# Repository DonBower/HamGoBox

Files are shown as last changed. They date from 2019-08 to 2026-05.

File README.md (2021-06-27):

# HamGoBox
Ham Radio Go Box

## Objectives:
The Purpose of this Repository is to document the build of the Ham Radio Go Box, which provides for an encapsulated radio that is already hooked up, and requires only power and an antenna.

## Status:
While the display and python3 code are working very well, there is one piece that needs attention: the humidity trend indicator (↑, →, ↓), needs attention.  it should not be changing from rising, stable, falling more than once an hour, but it changes mid minute.

Additionally, I need better documentation to set up the sensors.
Adafruit has made it very easy to install, and I need to reflect that in this repo.

Lastly, again on the documentation front, the STL files for the 3D printed objects need to be better documented.

## Components:
||||
|:---:|:---|:---|
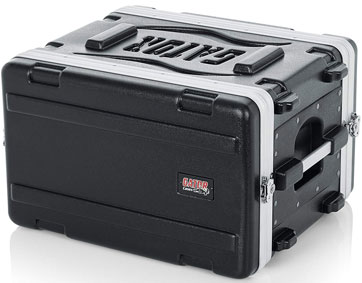
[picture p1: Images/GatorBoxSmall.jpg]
|  | [Gator Box](https://smile.amazon.com/gp/product/B0002BG4O8/ref=ppx_yo_dt_b_asin_title_o08_s04?ie=UTF8&psc=1) | This 6U Portable Rack keeps all of the equipment in one place, and connected. |
|  | [Shelf](https://smile.amazon.com/gp/product/B01C9KYUG8/ref=ppx_yo_dt_b_asin_title_o08_s01?ie=UTF8&psc=1) | The venting on these shelfs will allow for easy bolting down of equipment. |
|  | [Blank](https://smile.amazon.com/gp/product/B06Y1VJD6Q/ref=ppx_yo_dt_b_asin_title_o08_s03?ie=UTF8&psc=1) |These aluminum panels will provide a spot to add some meters, connectors and switches|
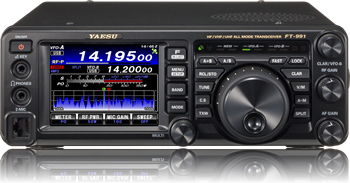
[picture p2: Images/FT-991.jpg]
||[FT-991](https://www.yaesu.com/indexVS.cfm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)|While this radio is no longer in production, a newer version (FT-991A) still is.  This Radio has  160M-6M, 2M & 70CM AM/FM/C4FM/SSB/CW.  There is also a digital mode, which lends this radio to doing PSK and other popular modes of communication.|
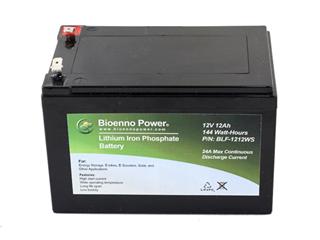
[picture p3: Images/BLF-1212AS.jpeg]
||[BATTERY](https://www.hamradio.com/detail.cfm?pid=H0-014837)|Lightweight 12 Volt/12 Ah battery based on state-of-the-art Lithium Iron Phosphate electrodes.|
|HF Antenna|[G5RVJR](https://www.hamradio.com/detail.cfm?pid=H0-008917)|40 through 6 meters dipole.|
|VHF/UHF Antenna|[NR-770HB](https://www.hamradio.com/detail.cfm?pid=H0-000063)|Diamond VHF/UHF Mobile Antenna.|
|Antenna Mast|[PNH-22](https://www.hamradio.com/detail.cfm?pid=H0-010315)|Lightweight 22' telescoping fiberglass mast.|
|Antenna Stand|[MFJ-1918](https://www.hamradio.com/detail.cfm?pid=H0-007037)|6 Foot Portable Tripod Antenna Stand.|
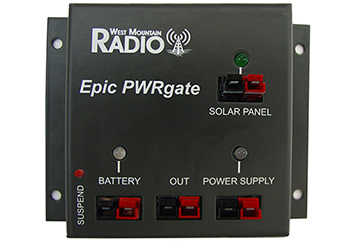
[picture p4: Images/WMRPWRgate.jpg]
||[WMR-Epic PWRgate](https://www.hamradio.com/detail.cfm?pid=H0-015910)|Consolidates power from Battery, Solar and Power Supply sources.  Charges Battery.|
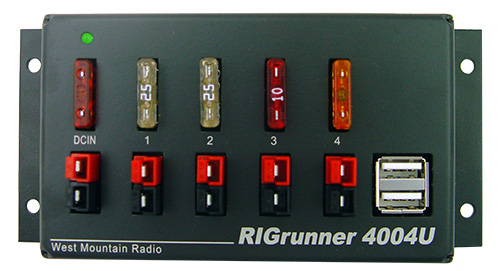
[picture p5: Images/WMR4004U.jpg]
||[WMR-4004U](https://www.hamradio.com/detail.cfm?pid=H0-009867)|Distributes fused power from Power Gate to various pieces of equipment, including Radio, Raspberry Pi, and Monitor.|
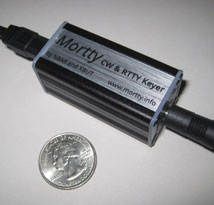
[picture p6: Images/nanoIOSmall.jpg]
||[Keyer](https://hamprojects.info/mortty/)|This Interface is used to enable True Keyed CW when using fldigi. This is a DIY kit, that requires soldering.|
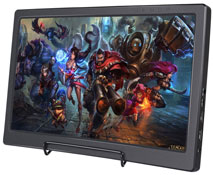
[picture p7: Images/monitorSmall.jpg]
||[Monitor](https://smile.amazon.com/gp/product/B07NNXH2SS/ref=ppx_yo_dt_b_asin_title_o00_s01?ie=UTF8&psc=1)|13 inch high res monitor.|
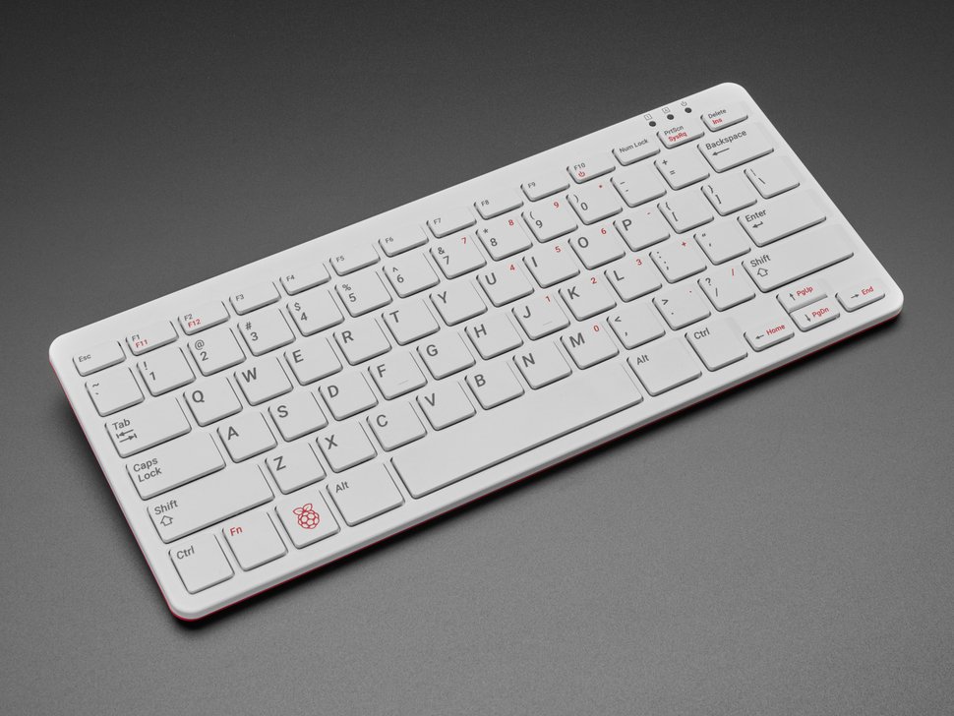
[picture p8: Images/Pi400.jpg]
||[Computer](https://www.adafruit.com/product/4796)|Yea, that's right Computer. With built in Keyboard.  or peraps the other way around. This computer in a keyboard will run all of the software for the Radio (PSK, Logbook, etc...), it has a USB port, a 40 pin GPIO, and and sd-micro for storage.|
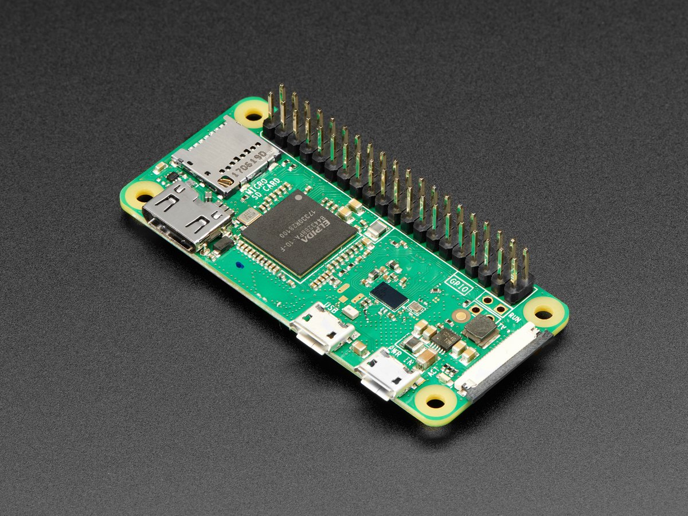
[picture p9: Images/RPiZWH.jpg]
||[Computer](https://www.adafruit.com/product/3708)|This half credit card size computer will run all of the environmental software, it has a USB port, a 40 pin GPIO, and and sd-micro for storage, and it's connected to a boat load of sensors.|
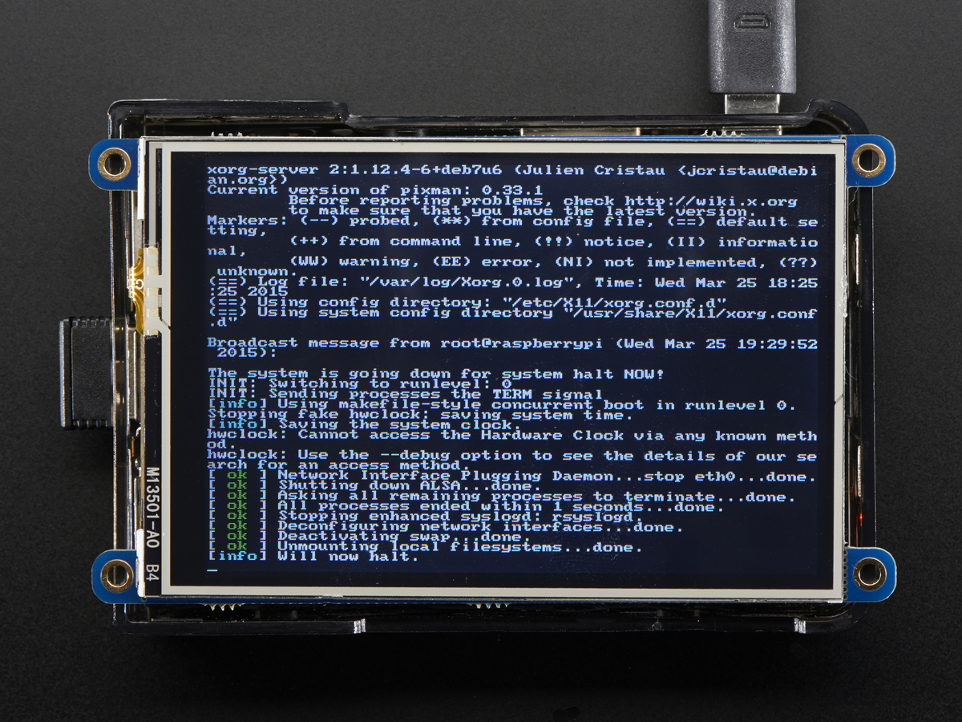
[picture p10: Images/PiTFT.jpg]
||[Display](https://www.adafruit.com/product/2441)|This Display is configured as the Console for the RaspberryPi. It will display all the Environmental information.|
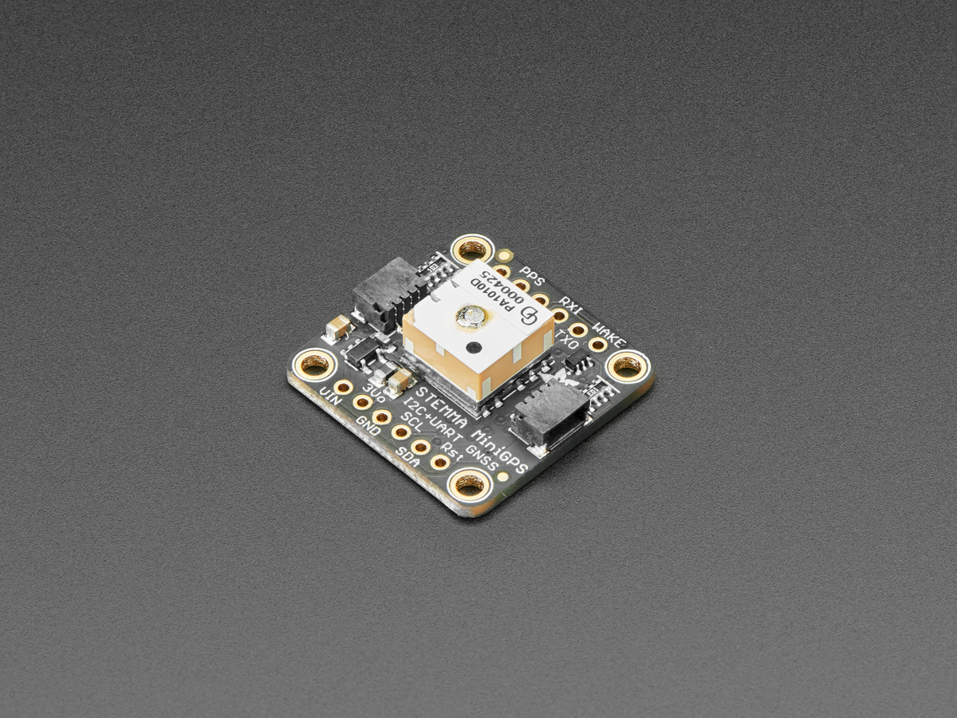
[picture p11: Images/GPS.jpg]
||[GPS Sensor](https://www.adafruit.com/product/4415)|Used to determine precise Latitude and Longitude. From this we can derive the Maidenhead Gridsquare.|
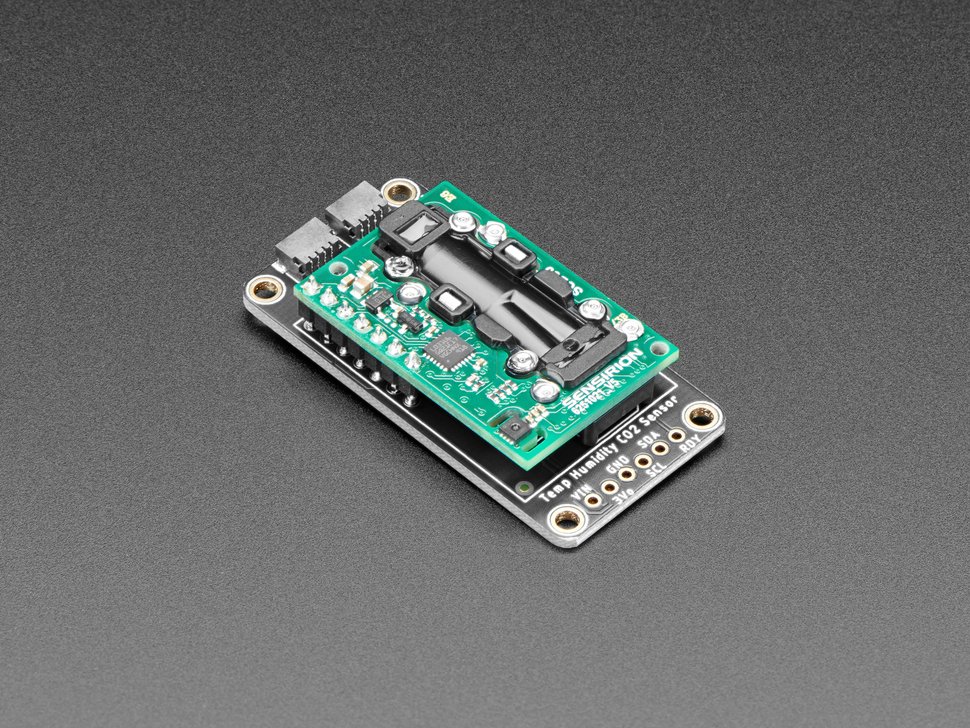
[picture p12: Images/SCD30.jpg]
||[CO2 Sensor](https://www.adafruit.com/product/4867)|The SCD-30 is an NDIR sensor, which is a 'true' CO2 sensor, that will tell you the CO2 PPM (parts-per-million) composition of ambient air. Unlike the SGP30, this sensor isn't approximating it from VOC gas concentration - it really is measuring the CO2 concentration. Perfect for environmental sensing, scientific experiments, air quality and ventilation studies, and more.|
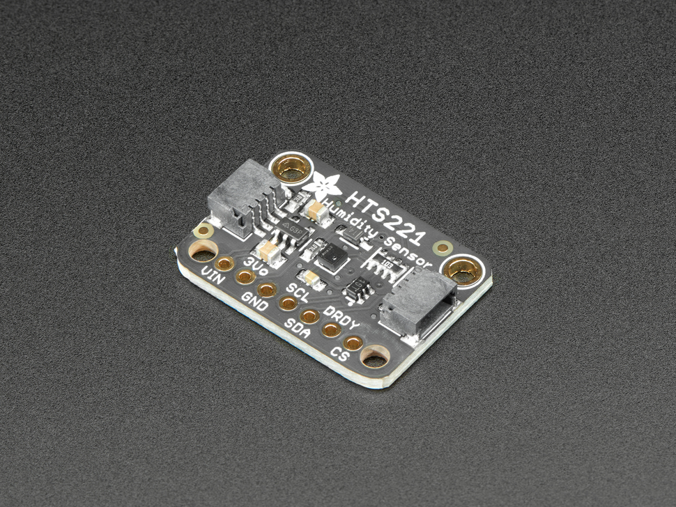
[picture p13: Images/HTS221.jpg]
||[Temperature and Humidity Sensor](https://www.adafruit.com/product/4535)|The HTS221 can measure relative humidity from 0%-100% rH with a sensitivity of 0.004% and 3.5% accuracy between 20-80%. It can also measure temperature from -40 to 120 degrees C, with a resolution of 0.016°C with ±0.5 °C accuracy between 15 and +40 °C.|
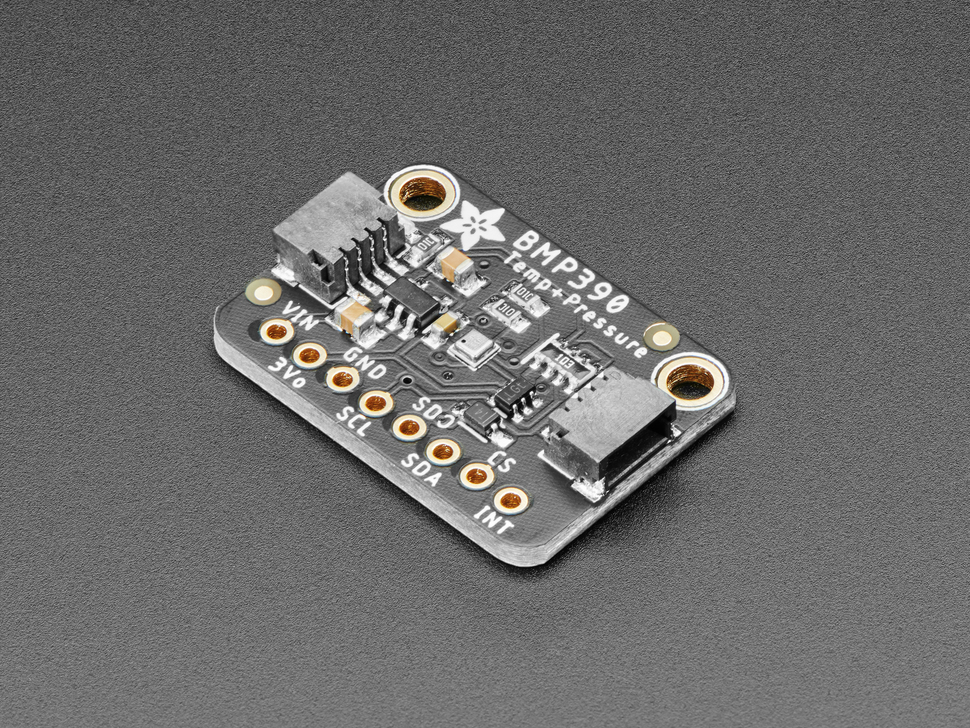
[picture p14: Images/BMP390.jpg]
||[Precision Barometric Pressure Sensor](https://www.adafruit.com/product/4816)|The BMP390L is the next-generation of sensors from Bosch, with a low-altitude noise as low as 0.1m and the same fast conversion time. This sensor has a relative accuracy of ±3 Pascals|
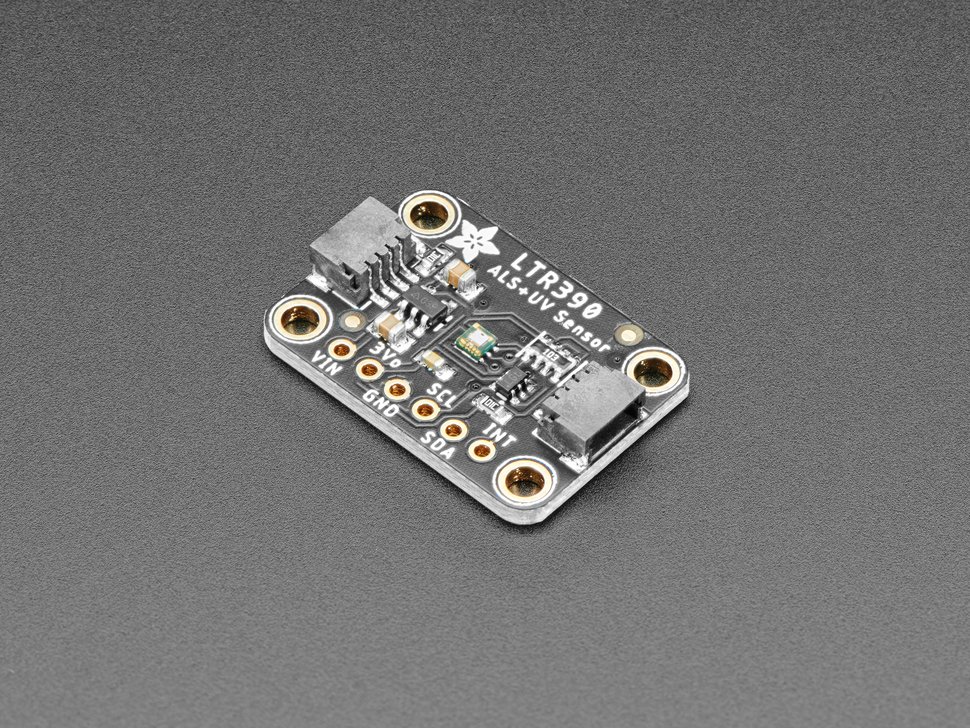
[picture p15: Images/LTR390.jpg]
||[UV Light Sensor](https://www.adafruit.com/product/4831)|The LTR390 has a dedicated  UVA sensor. With both ambient light and UVA sensing with a peak spectral response between 300 and 350nm.|
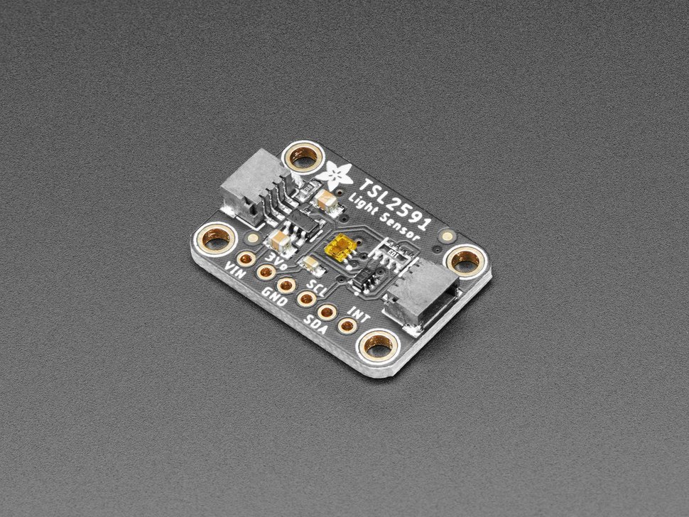
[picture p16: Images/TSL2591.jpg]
||[High Dynamic Range Digital Light Sensor](https://www.adafruit.com/product/1980)|The TSL2591 luminosity sensor is an advanced digital light sensor, ideal for use in a wide range of light situations. This Sensor has a dedicated IR light sensor|

<!---
|![alt text][wmrPNP]|[Interface](https://www.hamradio.com/detail.cfm?pid=H0-008403)|This Interface is capable of converting the audio from software sources such as Ham Radio Deluxe (windows onPNH)22https://www.hamradio.com/detail.cfm?pid=H0-010315.  It's also capable of True Keyed CW when used with HRD, but not fldigi.|
--->

---
## Future Wants
* Weather Conditions -rain? wind?
* Power Monitor V/A/W/Batt lifetime
* CAT Monitor
* Ext Speaker

---
## Assembly

---
## Software Installation
* Setup the RaspberryPi

1. OS. I am going to use Rasbian, the default OS for a RaspberryPi. Start by instsalling [NOOBs](http://downloads.raspberrypi.org/NOOBS_latest). The Setup is described in the [Pi](https://github.com/DonBower/HamGoBox/tree/master/Pi)

1. Programs. I am going to use fldig, flrig and wsjt-x. The Setup is described in [fldig](https://github.com/DonBower/HamGoBox/tree/master/fldigi) and [wsjt-x](https://github.com/DonBower/HamGoBox/tree/master/wsjtx)

1. Location. Precise location is always imperative. So we will use [Adafruit's GPS Hat](https://www.adafruit.com/product/2324). The Setup for this device is described in the [GPS Folder](https://github.com/DonBower/HamGoBox/tree/master/GPSHat)

2. Temperature and Humidity. We will be collecting this information with the [DHT22 Sensor](https://www.adafruit.com/product/385). Because Humidity has an effect on the rate of temperature change, it's important to collect the Relative Humidity. Setup will be found in the [DHT22 Folder](https://github.com/DonBower/HamGoBox/tree/master/DHT22)

3. Temperature and Barometric Pressure. Barometric Pressure also has an effect on Temperature, so we will use the [BMP280 Sensor](https://www.adafruit.com/product/2651) to collect this data.  Setup will be found in the [BMP280 Folder](https://github.com/DonBower/HamGoBox/tree/master/BMP280)

[gatorBox]: https://github.com/DonBower/HamGoBox/blob/master/Images/GatorBoxSmall.jpg "Field Day Box"

[gatorShelf]: https://github.com/DonBower/HamGoBox/blob/master/Images/ShelfSmall.jpg "Rack Shelf"

[gator1UPanel]: https://github.com/DonBower/HamGoBox/blob/master/Images/1UPanelSmall.jpg "Blank Panel"

[yaesuFT897D]: https://github.com/DonBower/HamGoBox/blob/master/Images/FT-897DSmall.jpg "Ham Radio"

[FT-991]: https://github.com/DonBower/HamGoBox/blob/master/Images/FT-991.jpg "Ham Radio"

[BATTERY]: https://github.com/DonBower/HamGoBox/blob/master/Images/BLF-1212AS.jpeg "12V12Ah LiFePo Battery"

[wmrPWRGate]: https://github.com/DonBower/HamGoBox/blob/master/Images/WMRPWRgate.jpg "Epic PWRGate"

[wmr4004U]: https://github.com/DonBower/HamGoBox/blob/master/Images/WMR4004U.jpg "RIGrunner 4004U"

[wmrPNP]: https://github.com/DonBower/HamGoBox/blob/master/Images/WMRPnPSmall.jpg "Digital Mode Interface"

[nanoIO]: https://github.com/DonBower/HamGoBox/blob/master/Images/nanoIOSmall.jpg "CW Keyer"

[raspberryPI]: https://github.com/DonBower/HamGoBox/blob/master/Images/RaspberryPiSmall.jpg "Raspberry Pi"

[raspberryPI400]: https://github.com/DonBower/HamGoBox/blob/master/Images/Pi400.jpg "Raspberry Pi 400"

[monitor]: https://github.com/DonBower/HamGoBox/blob/master/Images/monitorSmall.jpg "Monitor"

[raspberryPIZero]: https://github.com/DonBower/HamGoBox/blob/master/Images/RPiZWH.jpg "Raspberry Pi Zero"

[PiTFT]: https://github.com/DonBower/HamGoBox/blob/master/Images/PiTFT.jpg "Raspberry Pi TFT"

[GPS]: https://github.com/DonBower/HamGoBox/blob/master/Images/GPS.jpg "Mini GPS Sensor"

[SCD-30]: https://github.com/DonBower/HamGoBox/blob/master/Images/SCD30.jpg "NDIR CO2 Sensor"

[HTS221]: https://github.com/DonBower/HamGoBox/blob/master/Images/HTS221.jpg "Temperature & Humidity Sensor"

[BMP390]: https://github.com/DonBower/HamGoBox/blob/master/Images/BMP390.jpg "Precision Barometric Pressure and Altimeter Sensor"

[LTR390]: https://github.com/DonBower/HamGoBox/blob/master/Images/LTR390.jpg "UV Light Sensor"

[TSL2591]: https://github.com/DonBower/HamGoBox/blob/master/Images/TSL2591.jpg "High Dynamic Range Digital Light Sensor"

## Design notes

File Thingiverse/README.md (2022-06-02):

You can also find these .STL files on thingiverse:

[West Mountain Brackets](https://www.thingiverse.com/thing:4728897)

[Front Plate](https://www.thingiverse.com/thing:4786908)

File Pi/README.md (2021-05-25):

# Install the RaspberryPi Imager
Raspberry Pi Imager is the quick and easy way to install Raspberry Pi OS and other operating systems to a microSD card, ready to use with your Raspberry Pi. [Watch their 40-second video](https://www.youtube.com/watch?v=J024soVgEeM) to learn how to install an operating system using Raspberry Pi Imager.

Download and install Raspberry Pi Imager to a computer with an SD card reader. Put the SD card you'll use with your Raspberry Pi into the reader and run Raspberry Pi Imager.

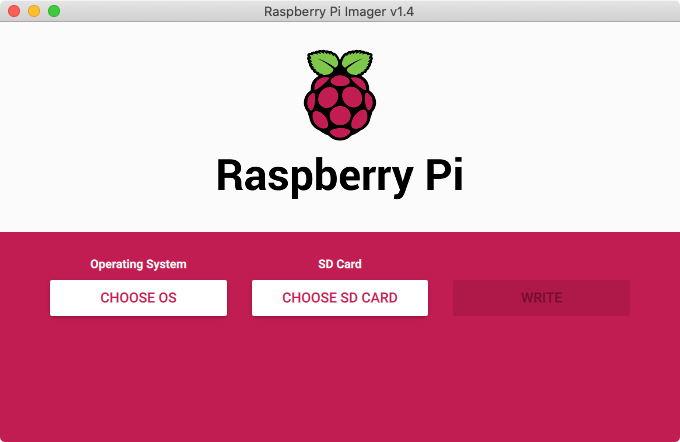
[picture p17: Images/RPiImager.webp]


Install the [RaspberryPi Imager](https://www.raspberrypi.org/software/):

* Install on another Raspberry Pi with GUI: run `sudo apt install rpi-imager` in a terminal window

* [Download for macOS](https://downloads.raspberrypi.org/imager/imager_1.5.dmg)

* [Download for Ubuntu_x86](https://downloads.raspberrypi.org/imager/imager_1.5_amd64.deb)

* [Download for Windows](https://downloads.raspberrypi.org/imager/imager_1.5.exe)

[Imager]: https://github.com/DonBower/HamGoBox/blob/master/Images/RPiImager.webp "RaspberryPi Imager"

# Install RasbianOS Lite
Be sure to choose the Lite Version of RasbianOS, because we will not be running a Gui from the RaspberryPi Zero.

Burn the OS image to your MicroSD card using your computer

Re-plug the SD card into your computer (don't use your Pi yet!)

Set up your wifi by copying the file [wpa_supplicant.conf](https://github.com/DonBower/HamGoBox/blob/master/Pi/wpa_supplicant.conf) to the sd card and then edit the file, replacing the <> values with your WiFi name and password.

Create an empty file called ssh on the sd card.
```
touch /Volumes/boot/ssh
```
This enables the ssh protocol on the RaspberryPi, which is good, because there is no GUI on this machine.

Eject the SD Card from your PC, and plug it into the Pi

If you have an HDMI monitor we recommend connecting it so you can see that the Pi is booting OK

Plug in power to the Pi - you will see the green LED flicker a little. The Pi will reboot while it sets up so wait a good 10 minutes

If you are running Windows on your computer, install Bonjour support so you can use .local names, you'll need to reboot Windows after installation

You can now ssh into raspberrypi.local
`ssh pi@raspberrypi.local`

# Set Hostname
```
sudo sed -i 's/raspberrypi/goboxpi/g' /etc/hosts
sudo sed -i 's/raspberrypi/goboxpi/g' /etc/hostname
sudo shutdown -r now
```

The Pi will reboot so log back in with `ssh pi@goboxpi.local`

# SSH Interface

Next order of business is get a ssh key. (Take all defaults)

```
ssh-keygen
```
Now, log out of the session with `exit` and copy the public key on your linux based machine to the RaspberryPi, so you don't have to use a password each time you log in.

```
ssh-copy-id -i ~/.ssh/id_rsa.pub pi@goboxpi.local
```

Copy the public SSH key to GitHub per the instructions documented in https://help.github.com/articles/adding-a-new-ssh-key-to-your-github-account/<br>

# Firmware/OS Updates

Next we update/upgrade the OS to the latest version, as well as the RaspberryPi Firmware.  <br />

```
sudo apt-get --assume-yes update
sudo rpi-update
```

At this point, your system may have actually performed a firmware update.  And a brave man may continue on and reboot later.  I am not that brave. `sudo shutdown -r now` if you are so inclined.

```
sudo apt-get --assume-yes upgrade
sudo apt-get --assume-yes dist-upgrade
sudo shutdown -r now
```

# Set Timezone

Set the Timezone

```
sudo timedatectl set-timezone America/Los_Angeles
```

# Git/GitHub

Then it's time to get git, and configure the git Global Variables <br />
(note: use your own name and email...)

```
sudo apt-get --assume-yes install git
git config --global user.name "Don Bower"
git config --global user.email "Don.Bower@outlook.com"
```

Next Create a *Developer* directory, and clone this repository from there.  The *Developer* directory is standard practice for modern developers. Some use lowercase for the name, but since on the RaspberryPi, and my Mac, all the other preloaded directories are capitalized, (i.e. Documents, Pictures, etc...) I'll follow form. <br />

```
mkdir ~/Developer
cd ~/Developer
git clone git@github.com:DonBower/HamGoBox.git
```

If you need updates from github, use git pull:

```
cd ~/Developer/HamGoBox
git pull
```

# Setup Tools

```
sudo pip3 install --upgrade setuptools
```
If above doesn't work, install pip3 and try again.

```
sudo apt-get install python3-pip
```
Adafruit put together a script to easily make sure your Pi is correctly configured and install Blinka. It requires just a few commands to run. Most of it is installing the dependencies.
```
cd ~
sudo pip3 install --upgrade adafruit-python-shell
wget https://raw.githubusercontent.com/adafruit/Raspberry-Pi-Installer-Scripts/master/raspi-blinka.py
sudo python3 raspi-blinka.py
```
select Y for any prompts.
after the RaspberryPi has rebooted, run this Test to confirm all the interfaces were installed and enabled

The [I&#x00B2;C (Inter-Integrated Circuit)](https://en.wikipedia.org/wiki/I%C2%B2C) and spi interfaces should now be installed and enabled.

You can run the following command to verify:
```
python3 Developer/HamGoBox/Pi/blinkatest.py
```

You can run the following command to verify:
```
ls /dev/i2c* /dev/spi*
```
You should see the response
```
/dev/i2c-1 /dev/spidev0.0 /dev/spidev0.1
```

# Python SMBUS and I&#x00B2;C Interface tools
To view the [I&#x00B2;C (Inter-Integrated Circuit)](https://en.wikipedia.org/wiki/I%C2%B2C)
devices that are connected, execute the following:
```
sudo i2cdetect -y 1
```
Your output will look similar to the following:
```
     0  1  2  3  4  5  6  7  8  9  a  b  c  d  e  f
00:          -- -- -- -- -- -- -- -- -- -- -- -- --
10: 10 -- -- -- -- -- -- -- -- -- -- -- -- -- -- --
20: -- -- -- -- -- -- -- -- -- 29 -- -- -- -- -- --
30: -- -- -- -- -- -- -- -- -- -- -- -- -- -- -- --
40: -- -- -- -- -- -- -- -- -- -- -- -- -- -- -- --
50: -- -- -- 53 -- -- -- -- -- -- -- -- -- -- -- 5f
60: -- 61 -- -- -- -- -- -- -- -- -- -- -- -- -- --
70: -- -- -- -- -- -- -- 77                         
```
all of the non "--" entries represent a device detected.

# Install CircuitPython Libraries for the sensors:

```
sudo pip3 install adafruit-circuitpython-gps \
 adafruit-circuitpython-bmp3xx \
 adafruit-circuitpython-hts221 \
 adafruit-circuitpython-tsl2591 \
 adafruit-circuitpython-ltr390 \
 adafruit-circuitpython-scd30
```

Test Which sensors are installed:
```
python3 ~/Developer/HamGoBox/Pi/sensortest.py
```

# Install TFT Display as the console.

```
cd ~
sudo pip3 install --upgrade adafruit-python-shell click==7.0
sudo apt-get install -y git
git clone https://github.com/adafruit/Raspberry-Pi-Installer-Scripts.git
cd Raspberry-Pi-Installer-Scripts
sudo python3 adafruit-pitft.py --display=35r --rotation=90 --install-type=console
```

# Install Blinka from Adafruit
```
cd ~
sudo pip3 install --upgrade adafruit-python-shell
wget https://raw.githubusercontent.com/adafruit/Raspberry-Pi-Installer-Scripts/master/raspi-blinka.py
sudo python3 raspi-blinka.py
```

# Get/Update Libraries from Adafruit
Run the following command to get the latest Libraries.
```
./getAdafruitLibraries.sh
```

It will product output that ends like this:
```
The Following Libraries were updated:

| Library                        | From   | To     |
| ------------------------------ | ------ | ------ |
| Adafruit-Blinka                | 5.13.0 | 6.9.1  |
| adafruit-circuitpython-bmp3xx  | 1.3.2  | 1.3.6  |
| adafruit-circuitpython-gps     | 3.6.7  | 3.9.0  |
| adafruit-circuitpython-hts221  | 1.1.2  | 1.1.5  |
| adafruit-circuitpython-scd30   | 2.0.0  | 2.1.0  |
| adafruit-circuitpython-tsl2591 | 1.2.5  | 1.3.0  |
| Adafruit-PlatformDetect        | 2.28.0 | 3.13.1 |
```

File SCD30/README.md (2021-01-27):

# CO2 Sensor

```
sudo pip3 install adafruit-circuitpython-scd30
```

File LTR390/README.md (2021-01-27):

# UV Light Sensor
```
sudo pip3 install adafruit-circuitpython-ltr390
```

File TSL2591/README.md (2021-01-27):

# TSL2591 Circuit Python library
```
sudo pip3 install adafruit-circuitpython-tsl2591
```

This is a simple python library for the Adafruit TSL2591 breakout board based on the [Arduino library](https://github.com/adafruit/Adafruit_TSL2591_Library) from Adafruit. It was developed to work on a Raspberry PI.

# INFO

Enabeling I2C on the Raspberry Pi. You should be fine by following the instruction on [Adafruit](https://learn.adafruit.com/adafruits-raspberry-pi-lesson-4-gpio-setup/configuring-i2c).

In the last step ('Testing I2C') you should see at least one connected device, your TSL2591 (most likely at 0x29 ).

## Installing ##

To install the python module you first need to install the ibffi-dev package, then compile the driver.

```
sudo apt-get install libffi-dev
sudo python setup.py install
sudo python3 setup.py install
```

## Quickstart ##

```
import tsl2591

tsl = tsl2591.Tsl2591()  # initialize
full, ir = tsl.get_full_luminosity()  # read raw values (full spectrum and ir spectrum)
lux = tsl.calculate_lux(full, ir)  # convert raw values to lux
print lux, full, ir
```

## License ##

Python files in this repository are released under the [MIT license](LICENSE.md).

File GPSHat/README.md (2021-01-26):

# I2C Usage:
```
sudo pip3 install adafruit-circuitpython-gps
```
Way cooler than using an onboard UART you have to futz with, but if you want to go that route:

# The Right UART
So Here is my quest to use the Adafruit Ultimate GPS which comes in 2 flavors,   <br>
one is a [breakout](https://www.adafruit.com/products/746), and the other is a [hat](https://www.adafruit.com/products/2324). <br>
The issue with these two products working straight out of the box (with the pi 3) are <br>
1. The UART configured to use the GPIO is disabled <br>
2. The default UART for the GPIO is a mini-UART (i.e. software assisted)<br>
3. The Hardware UART is enabled and configured to use bluetooth.<br>

There is a fantastic write-up on how to get things back on track, which I am ultimately going to follow:  <br>
http://spellfoundry.com/2016/05/29/configuring-gpio-serial-port-raspbian-jessie-including-pi-3  <br>
<br>
First, I am using a [Raspberry Pi 3+](https://www.adafruit.com/products/3055).

<br>
With the Jessie Version of Raspian on my Pi3, the default serial port configuration is:<br>

* `/dev/serial0 -> ttyS0`
  * a.k.a. mini-UART
  * Is configured for GPIO
  * Is disabled
  * uses the service getty to provide console access

* `/dev/serial1 -> ttyAMA0`
  * Is configured for bluetooth
  * Is enabled<br>

These points are demonstrated by displaying the current status of the serial ports:
```
pi@raspberrypi:~/balloon $ ls -l /dev/ser*
lrwxrwxrwx 1 root root 7 Aug 25 03:46 /dev/serial1 -> ttyAMA0
```
We enable the GPIO UART by adding the line `enable_uart=1` to the bottom of <b>/boot/config.txt</b> file and reboot.<br>
<br>
Now we can see both UARTs enabled, but backwards for our purposes:
```
pi@raspberrypi:~/balloon $ ls -l /dev/ser*
lrwxrwxrwx 1 root root 5 Aug 26 02:48 /dev/serial0 -> ttyS0
lrwxrwxrwx 1 root root 7 Aug 26 02:48 /dev/serial1 -> ttyAMA0
```
<br>
Now it's time to stop the console service, which is unnecessary for the balloon project:<br>

```
sudo systemctl stop serial-getty@ttyS0.service
sudo systemctl disable serial-getty@ttyS0.service
```
<br>

Now, let's not reference the console service in future boots.<br>
Remove the `console=serial0,115200` entry from the <b>/boot/cmdline.txt</b> file, and reboot.<br>
<br>
Here is my new <b>/boot/cmdline.txt</b> file:

```
dwc_otg.lpm_enable=0 console=tty1 root=/dev/mmcblk0p7 rootfstype=ext4 elevator=deadline fsck.repair=yes rootwait
```

<br>
Finally we can swap the bluetooth port with the mini-UART by adding the line `dtoverlay=pi3-miniuart-bt` to the bottom of <b>/boot/config.txt</b> and reboot. <br>
<br>

Viola!<br>

```
pi@raspberrypi:~ $ ls -l /dev/ser*
lrwxrwxrwx 1 root root 7 Aug 26 03:24 /dev/serial0 -> ttyAMA0
lrwxrwxrwx 1 root root 5 Aug 26 03:24 /dev/serial1 -> ttyS0
```

Next we need to install the GPS daemon, gpsd. To install gpsd, simply run the following commands from the console:
```
sudo apt-get update
sudo apt-get install gpsd gpsd-clients python-gps
```

This will install the required packages (an internet connection will be required for this step!)
Raspbian Jessie systemd service fix

Now, disable a systemd service that gpsd installs. This service has systemd listen on
a local socket and run gpsd when clients connect to it, however it will also interfere with other gpsd instances that are manually run (like in this guide).

To disable the gpsd systemd service by running the following commands:
```
sudo systemctl stop gpsd.socket
sudo systemctl disable gpsd.socket
```

After disabling the gpsd systemd service above you're ready to try running gpsd manually. Now run the following command to manually start gpsd and
point it at the GPS breakout on the USB serial adapter port:
```
sudo gpsd /dev/ttyAMA0 -F /var/run/gpsd.sock
```

... which will point the gps daemon to our GPS device on the onboard serial UART.

Testing it Out<br>
After a few seconds, gpsd should open up the proper socket and if the GPS has locked on to a minimum number of satellites, we should be able to get some data from the GPS module.
To test this, we can use the following command:
```
cgps -s
```

If you have a fix, you'll see something like the following information in the terminal window:
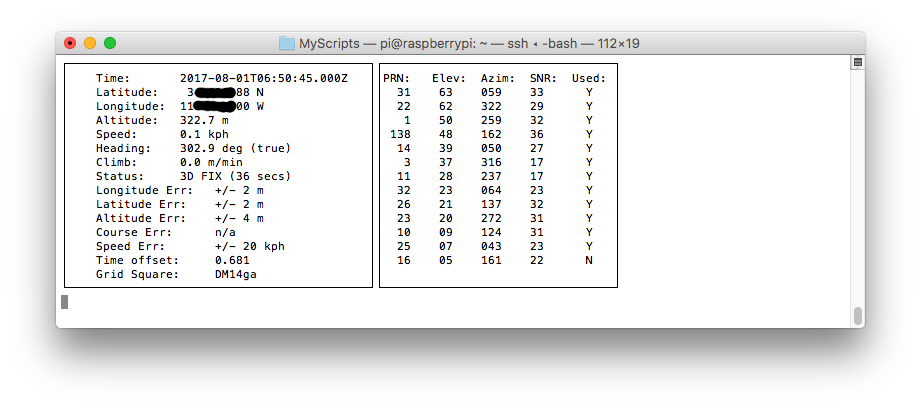
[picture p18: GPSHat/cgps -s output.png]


[logo]: https://github.com/DonBower/Eclipse2017/blob/master/GPSHat/cgps%20-s%20output.png "cgps -s output"

<br>

You will need to install a couple more packages to get the rungps.sh script to work:

```
sudo apt install bc
```
<br>

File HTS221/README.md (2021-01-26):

# Install Libraries

```
sudo pip3 install adafruit-circuitpython-hts221
```

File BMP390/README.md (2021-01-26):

# Tempature and Barametric Pressure sensor
Install with these commands<br>
```
sudo pip3 install adafruit-circuitpython-bmp3xx
```
Then you can run a simple test:
```
sudo python3 simpletest.py
```
Here is what mine looks like:
```
pi@raspberrypi:~/Adafruit_Python_BMP/examples $ sudo python simpletest.py
Temp = 24.50 *C
Pressure = 97255.00 Pa
Altitude = 343.12 m
Sealevel Pressure = 97270.00 Pa
```

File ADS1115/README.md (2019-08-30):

# ADS1115 Analog - Digital converter

# Adafruit Python ADS1x15
Python code to use the ADS1015 and ADS1115 analog to digital converters with a Raspberry Pi or BeagleBone black.

## Installation

To install the library from source (recommended) run the following commands on a Raspberry Pi or other Debian-based OS system:

    sudo apt-get install git build-essential python-dev
    cd ~/Developer/github/adafruit
    git clone https://github.com/adafruit/Adafruit_Python_ADS1x15.git
    cd Adafruit_Python_ADS1x15
    sudo python setup.py install

Alternatively you can install from pip with:

    sudo pip install adafruit-ads1x15

Note that the pip install method **won't** install the example code.

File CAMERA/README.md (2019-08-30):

CAMERA CONFIGURATION

SETTING UP THE CAMERA HARDWARE

Warning: Cameras are sensitive to static. Earth yourself prior to handling the PCB. A sink tap or similar should suffice if you don’t have an earthing strap.

The camera board attaches to the Raspberry Pi via a 15-way ribbon cable. There are only two connections to make: the ribbon cable needs to be attached to the camera PCB, and to the Raspberry Pi itself. You need to get the cable the right way round, or the camera will not work. On the camera PCB, the blue backing on the cable should face away from the PCB, and on the Raspberry Pi it should face towards the Ethernet connection (or where the Ethernet connector would be if you're using a model A).

Although the connectors on the PCB and the Pi are different, they work in a similar way. On the Raspberry Pi itself, pull up the tabs on each end of the connector. It should slide up easily, and be able to pivot around slightly. Fully insert the ribbon cable into the slot, ensuring it is set straight, then gently press down the tabs to clip it into place. The camera PCB connector also requires you to pull the tabs away from the board, gently insert the cable, then push the tabs back. The PCB connector can be a little more awkward than the one on the Pi itself.

SETTING UP THE CAMERA SOFTWARE

Execute the following instructions on the command line to download and install the latest kernel, GPU firmware, and applications. You'll need an internet connection for this to work correctly.

```
sudo apt-get update
sudo apt-get upgrade
```

Now you need to enable camera support using the raspi-config program you will have used when you first set up your Raspberry Pi.

```
sudo raspi-config
```

Use the cursor keys to move to the camera option, and select 'enable'. On exiting  raspi-config, it will ask to reboot. The enable option will ensure that on reboot the correct GPU firmware will be running with the camera driver and tuning, and the GPU memory split is sufficient to allow the camera to acquire enough memory to run correctly.

To test that the system is installed and working, try the following command:

```
raspistill -v -o test.jpg
```

The display should show a five-second preview from the camera and then take a picture, saved to the file `test.jpg`, whilst displaying various informational messages.

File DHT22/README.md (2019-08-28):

# DHT-22 Tempature and humidity sensor
Install the Adafruit DHT library:
```
git clone https://github.com/adafruit/Adafruit_Python_DHT.git
cd Adafruit_Python_DHT
sudo python setup.py install
```
Not much to that!

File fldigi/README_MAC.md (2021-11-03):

# Connect FLDIGI on the Macbook Pro with Big Sur (11.5.2) to Yaesu FT-991 (non-A)

## Load CP210x VCP Drivers 
If you have not already done so, or did with a version prior to 6.0.1, follow these steps 
1. Disconnect everything from the MacBook except LAN/WiFi
1. Reboot.
1. Download **CP210x VCP Mac OSX Driver** from [Silicon Labs Download page](https://www.silabs.com/developers/usb-to-uart-bridge-vcp-drivers)
1. Unzip the `Mac_OSX_VCP_Driver.zip` file
1. Launch the `SiLabsUSBDriverDisk.dmg` file by double clicking on it from **Finder**
    1. If you have a previous version of the driver, 
        1. Double click the uninstaller.sh and follow the prompts.
        1. Reboot, and follow the next step.
    1. Double click the `Install CP210x VCP Driver.app` file
        1. Follow the Prompts
1. Reboot.

## Configure the Radio
To Configure the Radio, you can change the Menu items as follows. In the Menu, default values appear as blue.
|Menu Item #|Menu Item Name|Item Value Range|Default Value|Prefered Value|
|---:|:---|---|---|:---:|
|31|CAT RATE|4800/9600/19200/38400 bps|4800 bps|**38400 bps**|
|32|CAT TOT|10/100/1000/3000 msec|10 msec|10 msec|
|33|CAT RTS|ENABLE/DISABLE|ENABLE|ENABLE|
|46|AM OUT LEVEL|0-100|50|**100**|
|59|CW FREQ DISPLAY|DIRECT FREQ/PITCH OFFSE|PITCH OFFSE|PITCH OFFSE|
|60|PC KEYING|OFF/DAKY/RTS/DTR|OFF|**DTR**|
|62|DATA MODE|PSK/OTHERS|PSK|**OTHERS**|
|63|PSK TONE|1000/1500/2000 Hz|1000 Hz|**1500 Hz**|
|64|OTHER DISP (SSB)|-3000 - 0 - 3000 10Hz Step|0 Hz|**1500 Hz**|
|65|OTHER SHIFT (SSB)|-3000 - 0 - 3000 10Hz Step|0 Hz|**1500 Hz**|
|66|DATA LCUT FREQ|OFF/100-1000 (50Hz Step)|300 Hz|300 Hz|
|67|DATA LCUT SLOPE|6 dB/oct / 18 dB/oct|18 dB/oct|18 dB/oct|
|68|DATA HCUT FREQ|700-4000 (50Hz Step)|3000 Hz|**3600 Hz**|
|69|DATA HCUT SLOPE|6 dB/oct / 18 dB/oct|18 dB/oct|18 dB/oct|
|70|DATA IN SELECT|REAR/MIC|REAR|REAR|
|71|DATA PTT SELECT|DAKY/RTS/DTR|DAKY|**DTR**|
|72|DATA PORT SELECT|DATA/USB|DATA|**USB**|
|73|DATA OUT LEVEL|0-100|50|**100**|
|74|FM MIC SELECT (PHONE)|MIC/REAR|MIC|MIC|
|75|FM OUT LEVEL|0-100|50|50|
|76|FM PKT PTT SELECT|DAKY/RTS/DTR|DAKY|**DTR**|
|77|FM PKT PORT SELECT|DATA/USB|DATA|DATA|
|106|SSB MIC SELECT|MIC/REAR|MIC|MIC|
|107|SSB OUT LEVEL|0-100|50|50|
|108|SSB PTT SELECT|DAKY/RTS/DTR|DAKY|DAKY|
|109|SSB PORT SELECT|DATA/USB|DATA|**USB**|
|110|SSB TX BPF|100-3000/100-2900/200-2800/300-2700/400-2600|300-2700|300-2700|
|114|IF NOTCH WIDTH|NARROW/WIDE|WIDE|**NARROW**|
|141|TUNER SELECT|OFF/INTERNAL/EXTERNAL/ATAS/LAMP|INTERNAL|**ATAS**|
|146|DATA VOX GAIN|0-100|50|50|
|147|DATA VOX DELAY	100|30-3000 msec|100 msec|100 msec|
|148|ANTI DVOX GAIN|0-100|0|0|
||||||

## Connect the FT-991 Radio
Use the [RT-42 USB-A to USB-B 6-Ft Cable](https://www.rtsystemsinc.com/RT-42-USB-A-to-USB-B-6-Ft-Cable_p_542.html) cable from RT Systems<br>
Open a terminal window and type `ls -l /dev/cu.*`
you should see the following:
```
don@MacbookPro ~ % ls -l /dev/cu.*
crw-rw-rw-  1 root  wheel    9,   1 Sep 14 15:31 /dev/cu.Bluetooth-Incoming-Port
crw-rw-rw-  1 root  wheel    9,   3 Sep 14 16:54 /dev/cu.SLAB_USBtoUART
crw-rw-rw-  1 root  wheel    9,   5 Sep 14 17:37 /dev/cu.SLAB_USBtoUART2
```

The FT-991, and other radios that have an intergrated sound card (FTdx-3000, FTdx-10D), along with the SCU-17 contain two virtual COM ports, an Enhanced COM port and a Standard COM Port, which are rendered by the SiliconLabs VCP Driver as `/dev/cu.SLAB_USBtoUART` and `/dev/cu.SLAB_USBtoUART2`  These ports offer the following functions:
  * CAT communications..................: Enhanced COM Port
  * TX control (PTT, KEY, FSK)..........: Standard COM Port

`<rant>`<br>
For the macOS Big Sur, it is not possiable, as it is in Windows, along with Ubuntu, Raspberry PI and other Linux distributions, to coerce the driver to render one to `/dev/cu.SLAB_USBtoUART` and the other to `/dev/cu.SLAB_USBtoUART2` at this time.

These devices can "swap" themselfs between macOS boots and reconnection of the radio.
if you examine the System Information for USB, you will see:
```
CP2105 Dual USB to UART Bridge Controller:

  Product ID:	0xea70
  Vendor ID:	0x10c4  (Silicon Laboratories, Inc.)
  Version:	1.00
  Serial Number:	AH057M5I150492
  Speed:	Up to 12 Mb/s
  Manufacturer:	Silicon Labs
  Location ID:	0x14110000 / 2
  Current Available (mA):	500
  Current Required (mA):	100
  Extra Operating Current (mA):	0
```
with the only indication that there are 2 devices here is the `/ 2` at `Location ID:`.

Given that other operating systems are able to coerce and/or identify these two different ports, one can only conclude Silicon Labs has not invested enough effort into this issue, nor is Apple innocent in removing the udev functionality. 
<br>`</rant>`

## Configure flrig 1.4.2
1. Download [flrig 1.4.2](http://www.w1hkj.com/files/flrig/flrig-1.4.2_bs.dmg) for Big Sur.
- _bs is for Big Sur, 11.x
- _hs is for macOS High Sierra, 10.13.x 
- _lion is for macOS Lion, 10.7.x
1. Open the .dmg file and copy the app to your /Applications folder
1. Open the flrig application from the Launchpad
1. Open the Config menu and select Setup>Transceiver<br>
Set the values as show in the graphic:
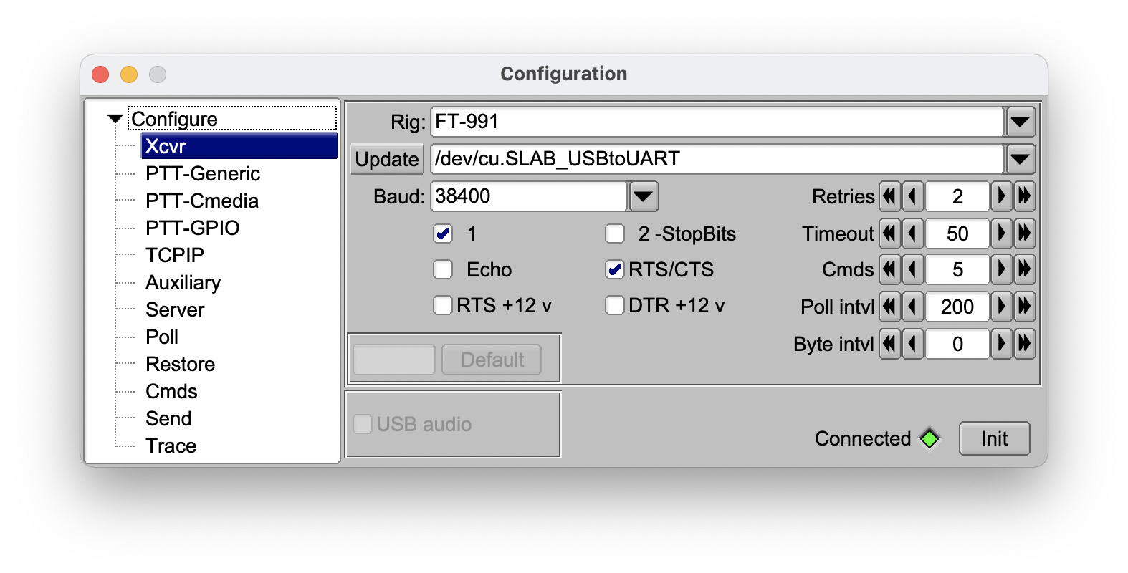
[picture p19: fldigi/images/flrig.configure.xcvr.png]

1. Click the [init] button<br>
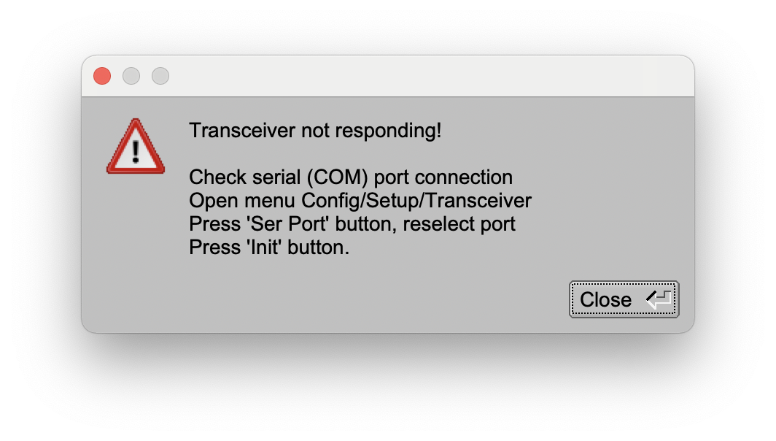
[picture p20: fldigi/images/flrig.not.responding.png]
If you this pop-up <br> then choose the other cu.SLAB device.  It is not possiable at this time to configure the macbook to predict which cu.SLAB device is the "enhanced" port, which provides CAT operations with the radio.  In fact, this assignment can change between reboots of the computer, and re-connection of the radio.  It's a huge dis-advantage to macOS, which Windows, Ubuntu and Raspberry Pi are able to deal with for better consistancy.
So if your radio works today, but won't conecct tomorrow, swap these two values, and click the [init] button again.<br>
1. Select Setup>PTT-Generic from the Config menu<br>
Set the values as show in the graphic:
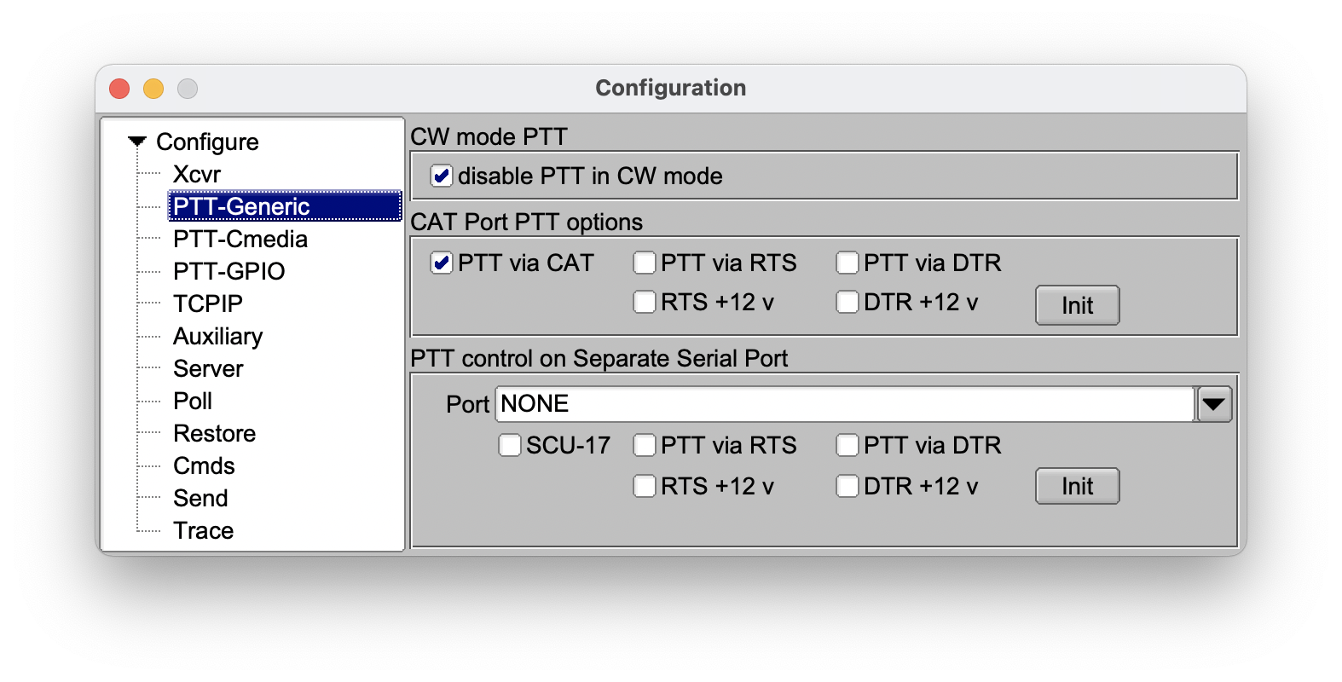
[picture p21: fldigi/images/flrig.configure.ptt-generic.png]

1. Select Setup>TCPIP from the Config menu<br>
Set the values as show in the graphic:
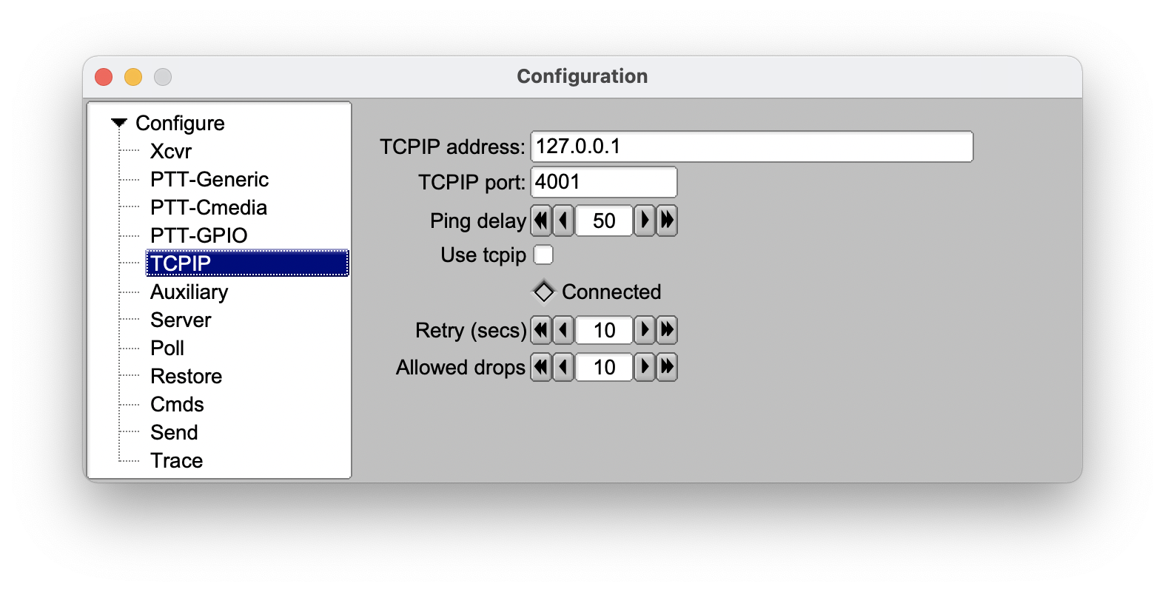
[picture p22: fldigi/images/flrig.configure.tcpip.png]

1. Select Setup>Poll from the Config menu<br>
Set the values as show in the graphic:
![alt-text][flrig.config.poll]
1. Select Setup>Restore from the Config menu<br>
Set the values as show in the graphic:
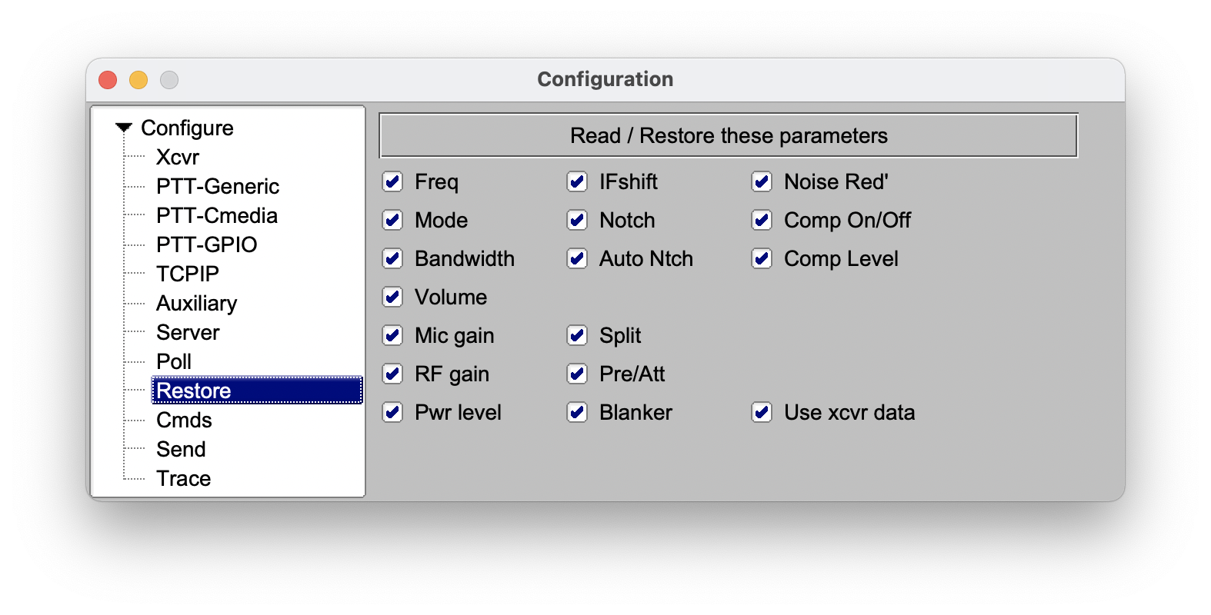
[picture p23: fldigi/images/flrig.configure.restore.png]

<br>
When Complete, close the Configuartion Pop-Up, and you should see this:
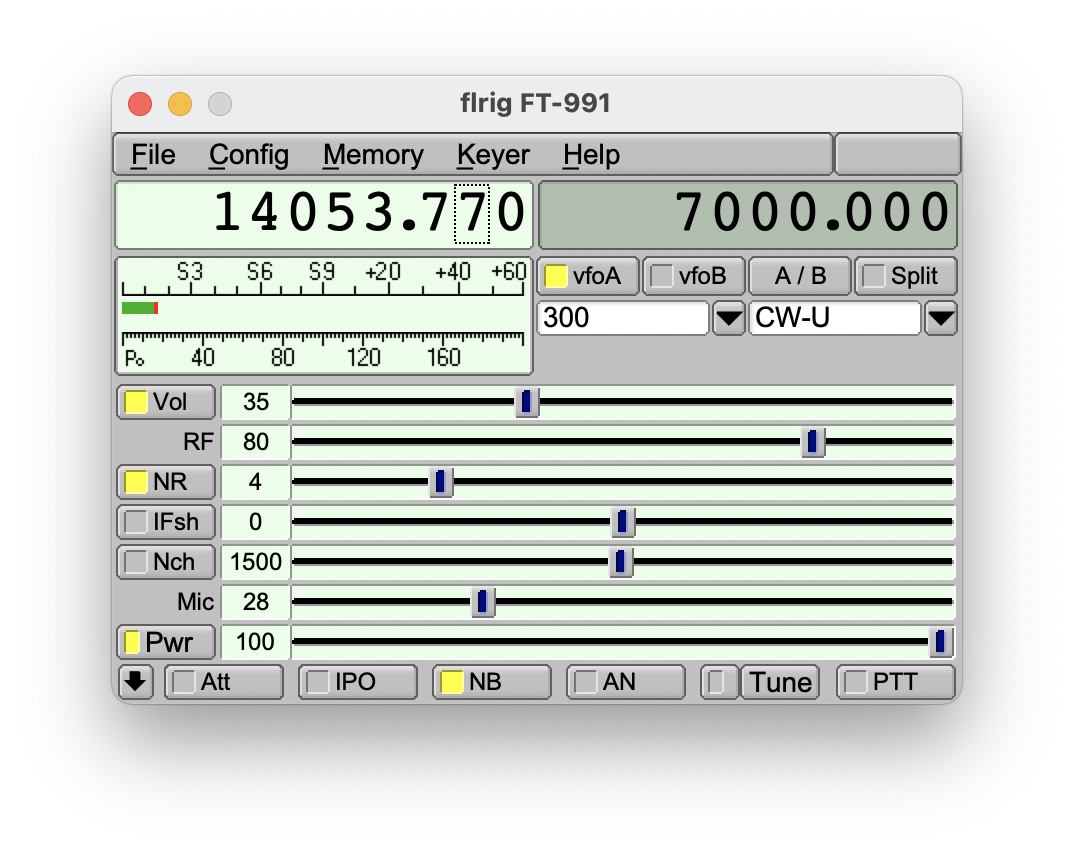
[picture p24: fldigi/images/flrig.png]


## Configure fldigi 4.1.20
1. Download [fldigi 4.1.29](http://www.w1hkj.com/files/fldigi/fldigi-4.1.20_bs.dmg) for Big Sur.
- _bs is for Big Sur, 11.x
- _hs is for macOS High Sierra, 10.13.x 
- _lion is for macOS Lion, 10.7.x
1. Open the .dmg file and copy the app to your /Applications folder
1. Open the fldigi application from the Launchpad

## Using the FT-991A with fldigi and flrig

CAT control involves both software and settings on the radio itself. The default radio settings on the FT-991 are not likely to work “out of the box”.

Some initial things to verify are in place:

1. Download and install the USB driver for the radio. NOTE: be sure the USB cable is UNPLUGGED from the
computer when you install the driver regardless of the OS your are using.
- If you’re using Windows get the driver from Icom or use the one on the CD that comes with the radio.
- If using Linux or MacOS then get the drivers direct from [Silcon Labs]([https://www.silabs.com/products/development-tools/software/usb-to-uart-bridge-vcp-drivers). Note: Some versions of Linux have a driver
built in.

Note: For MacOS High Sierra and later be sure to go to Security & Privacy in the System Configuration
settings and in the General tab allow the driver to be accessed. Without doing that it will be unusable.

2. Download the latest version of Fldigi. I also highly recommend downloading flrig
for transceiver control. Flrig is written as a companion to fldigi and adds much greater rig control than is possible with just fldigi. It is especially good with the FT991A. I basically only touch the radio to turn it on or off when running digital modes, and even that can be automated.

Download both from [W1HKJ web site](www.w1hkj.com).

It is highly recommend that you also download the flrig and fidigi help pdf files from the  [W1HKJ web site](www.w1hkj.com)  website. They are well written help files. Fldigi's help is hundreds of pages long and has a great deal of helpful info. When you get to installing fldigi it will be a big help to you and should guide you in the setting of the necessary and optional parameters. Once it’s running there are so many features to use that are not always obvious that reading it or at least a detailed scan through it should be a goal.

### FT-991A settings

On the rig, press the MENU button.  Then change these menu items as shown:

Menu # | Name | Value
---------- | ---------- | ------ 
31	 | CAT RATE	 | 38400 bps
32	 | CAT TOT	 | 10 msec
33	 | CAT RTS	 | ENABLE
59	 | CW FREQ DISPLAY	 | PITCH OFFSET
60	 | PC KEYING	 | DTR
62	 | DATA MODE	 | OTHERS
63	 | PSK TONE	 | 1500 hZ
64	 | OTHER DISP (SSB)	 | 1500 Hz
65	 | OTHER SHIFT (SSB)	 | 1500 Hz
66	 | DATA LCUT FREQ	 | 300 Hz
67	 | DATA LCUT SLOPE	 | 18 dB/oct
68	 | DATA HCUT FREQ	 | 3600 Hz
69	 | DATA HCUT SLOPE	 | 18 dB/oct
70	 | DATA IN SELECT	 | REAR
71	 | DATA PTT SELECT	 | DAKY
72	 | DATA PORT SELECT	 | USB
73	 | DATA OUT LEVEL (RX)	 | 100
74	 | FM MIC SELECT (PHONE)	 | MIC
75	 | FM OUT LEVEL (Rx)	 | 50
76	 | FM PKT PTT SELECT	 | DTR
77	 | FM PKT PORT SELECT	 | DATA
106	 | SSB MIC SELECT	 | MIC
107	 | SSB OUT LEVEL	 | 50
108	 | SSB PTT SELECT	 | DAKY
109	 | SSB PORT SELECT	 | USB
110	 | SSB TX BPF	 | 300-2700
114	 | IF NOTCH WIDTH	 | NARROW
146	 | DATA VOX GAIN	 | 50
147	 | DATA VOX DELAY	 | 100 msec
148	 | ANTI DVOX GAIN	 | 0

### Software setup
You should have already installed the driver for the built-in sound card in the FT-991A.

Connect the rig to the computer with a USB A-Male to B-Male cable and turn on the radio.

Install fldigi and flrig.  On Windows the programs install to their own folders and should be installed in the normal application directory where other apps are installed. Putting them in other folders can causes permissions issues sometimes on Windows 10. For Mac and Linux install them as you would any other application.For those choosing to use flrig continue below, otherwise scroll down to the RigCat setup:

### flrig control option
First, we get flrig going then it’s easy to configure fldigi to use flrig for xcvr control.

With the radio on and the USB cable connected and no other communications program running, Start flrig.  It will come up with just a basic display. 

Go to the menu

Config/Setup/Transceiver.
<center>
[[alt-text][flrig.config.xcvr]]
</center>
Choose the FT991A from the Rig dropdown list. That will select the default settings which will work on . Note: The RTS +12v and DTR +12v boxes do not normally need to be checked.

#### Now choose the Serial Port to use
###### Mac / Linux
Select the SilconLabs driver from the dropdown list. If it isn't in the list then click the SerPort button to repopulate the list. It if still isn't in the list then the driver is not loading for some reason like the radio is not on or connected or the driver has not been installed properly so that needs to be rectified before going on. If you're using MacOS High Sierra or a later version of MacOS you may need to authorize the driver install in Security & Privacy setup in System Preferences after runing the install program. There will be a message on the General page if it has been blocked.
###### Windows 
Open the device manager and determine to which com port the serial driver from Silcon Labs is assigned and choose that from the drop down list. Verify that the Baud rate in flrig matches the baud rate selected in the rig. It's better to choose a fixed baud rate than Auto.  Now, click the Init button. It should go from red to black lettering. If it does not go to black lettering then verify all of the above again, especially baud rate and echo.

Next select the restore tab
<center>
[]
</center>
and choose whether you want flrig to save and restore all the radio’s parameters on startup and exit or whether you want it to open with the same settings as the rig is currently using.  If Use xcvr data is checked flrig will start up with the same settings as the rig currently is using.

Select the poll tab
<center>

</center>
and click the Set All buttons for the initial polling options. You can play with these values later if you wish. The larger the number the slower the response time to button pushes etc, but also the less load on the system so there is a balance. A very fast machine can use all ones, but there is normally no need to add the additional load to your system for that.

Flrig now should have control of the rig so changing frequency in flrig will changed the frequency on the rig and visa versa. The buttons and sliders should do as they are labeled.

I would recommend before you move on that you go to the Config/UI menu and select Tooltips. They are a great help to the new user to figure out what each control does as not all are labeled.  You can choose 4 different UI’s from the narrow one with small sliders (I use this one – see above screen shot of flrig), to a narrow one with large sliders, to a wide version or a touch version.  Now close flrig and restart it to be sure all is well . Everything should be working and you should be able to change frequency on the radio and flrig should follow.

Configure fldigi for use with flrig/FT991A.

Start fldigi and fill in the initial setup pages presented. You can ignore the last page for now. All these pages can be accessed via the configuration menu later to be changed as you wish.  Since you've chosen to use flrig then go to the fldigi menu “Configuration/Rig control/flrig” and check the top box to tell fldigi to use flrig for rig control with fldigi as client.   Leave the other controls at their default setting.
<center>

</center>
Once that is done fldigi should communicate with flrig and changes such as frequency or bandwidth in flrig or fldigi should be reflected in the other. If the lower box is checked then flrig will send fldigi audio to the radio when the PTT button is clicked otherwise PTT will just key the rig with no power out. Click Save at the bottom of the page.

Setup DATA-U as the mode and bandwidth as 3000 for now.
<center>

</center>
All that is left is to customize fldigi for how you want to operate. Many things can be changed such as the UI scheme, colors, Macros, and many more. Read the help manual to learn about all the options and features that are available.
> [flrig manual as pdf file](http://www.w1hkj.com/files/flrig/flrig-help.pdf)
> [on-line html manual](http://www.w1hkj.com/flrig-help/)

### RigCat rig control option
To setup RigCat you first must download the IC7100.xml file and save it to the “Rigs” directory of the fldigi directory .

[FT991A xml file](http://www.w1hkj.com/files/xmls/yaesu/FT-991A.xml)

###### Mac/Linux
Put the file in $HOME/.fldigi/rigs/
###### Windows
Open the file finder.  Find the fldigi.files directory and put it in the rigs directory. Where the fldigi.files directory is different depending on the version of Windows. It is normally under the user's name.  Once the IC7100.xml file is in place then start fldigi. It will run you through the basic setup pages.  Ignore the last setup page for now.

Start fldigi and after it is up and running
<center>

</center>
with the basic setup then from the menu choose from the menu Configuration/Rig control/RigCat. At the upper left “Rig description” click Open and choose the IC7100.xml file already downloaded. Once the rig description file is selected then verify that the Baud Rate is the same as the radio.

Choose the Device from the drop down list. On Mac or Linux there should be a device for the SilLab USBtoUart. On Windows check the device manager in Windows to see which Com port is assigned to the USB-Uart device on the radio. and then choose that Com port.

Verify that the only check boxes checked are Commands are Echoed, CAT command for PTT, and Restore Settings on close.

Check the box at the top to “Use RigCat” and then click Initialize. The lettering should go from red to black. At this point you should have rig control from fldigi and changing frequencies in fldigi should be reflected on the radio and visa versa. Set the bandwidth desired and mode to DATA-U for digital mode use in fldigi.
<center>
[[img src=ft991a-fldigi-mode-bw.png ]]
</center>
### Final Setup

With fldigi running verify you have a blue waterfall running. If you don't see that then there is a problem with the audio input to fldigi. Verify the Soundcard setup.

Note:
  * For MacOS Mojave and later you must enable the microphone for fldigi in Security & Privacy in the System Preferences settings.
  * For Windows 10 be sure to grant permission for fldigi to access the Microphone.

Now we will verify the power out of the radio. Set the radio power control on the rig to max, 100%
and leave it there.

Set Power Meter scale:
  * Flrig: Right click on the lower portion of the S-meter scale and choose the power scale desired.  
  * RigCat: Menu – Configuration>UI>Clrs/Fnts>FreqDisp/Meters. Choose power scale and Save.

Note: The max digital power out used for a QSO should cause no ALC action on the radio. The FT991A will put out quite a bit of power without ALC action, but you don't want to interfere with other close signals on the band either so ideally the power should be between 25-40 watts.

Fldigi has a Transmit Attenuator at the lower right of the fldigi window and this is used to make small adjustments in power. I set mine at 9 then adjust the radio's menu item, USB MOD Level to get 30 watts of power. This allows you to add more power or reduce power as needed in fldigi with the Transmit Attenuator without touching the radio. Note: Higher numbers in the attenuator mean lower output.

Note: In Windows there is the Windows Mixer that is also in the audio stream so that will need to be included in the audio level adjustments in and out for the radio's built-in sound card.

Now click on the Tune button in fldigi upper right corner. That should put the rig into transmit. The actual power output will be dependent on the audio drive to the radio. Adjust the audio stream as described above to get about 30 watts of power with the transmit attenuator set to what ever you choose for a default number. Fldigi defaults to 3.

You should now have working copies of flrig and fldigi and be ready for a digital QSO.

Checkout the default macros. Feel free to customize them and also setup a few macros for those personal information things you always want to send like, Name, Signal report, QTH, Grid Loc, your station configuration etc. It's your software and station so set it up as you wish. Remember to read the manuals. You'll learn how to make so much better use of this fantastic software and radio.

The waterfall appearance may be adjusted by the numbers at the bottom left under the waterfall.  Default settings are 0 and 60. You may want to raise the 60 to 70 to increase the contrast. Feel free to adjust the numbers for the look you like best.

Now that you’re up and running, there are two things that need to be done to get the best decoding:

  - Adjust the receive audio level. Fldigi-help.pdf, Paragraph 2.9, pg 20
  - Calibrate the sound card. Fldigi-help.pdf, Paragraph 6.3, pg 295

<style type="text/css">
   /* Indent Formatting */
   /* Format: 1-A-I-1-a-i */
   ol {list-style-type: decimal;}
   ol ol { list-style-type: upper-alpha;}
   ol ol ol { list-style-type: upper-roman;}
   ol ol ol ol { list-style-type: decimal;}
   ol ol ol ol ol { list-style-type: lower-alpha;}
   ol ol ol ol ol ol { list-style-type: lower-roman;}
   /* https://www.w3schools.com/cssref/pr_list-style-type.asp */
   /* https://stackoverflow.com/questions/11445453/css-set-li-indent */
   /* https://stackoverflow.com/questions/13366820/how-do-you-make-lettered-lists-using-markdown */
</style> 

[FT991DU]: images/FT991DU.jpeg "FT-991 in Data-USB mode"

[fldigi.config.soundcard.devices]: images/fldigi.config.soundcard.devices.png "fldigi Config/Sound Card values""

[fldigi.config.operator-station]: images/fldigi.configure.operatior-station.png "fldigi Config/Operation-Station values"

[fldigi.config.rig-control.flrig]: images/fldigi.configure.rig-control.flrig.png "fldigi Config/rig-controll flrig"

[fldigi.config.rig-control.flrig2]: images/fldigi.configure.rig-control.flrig2.png "fldigi Config/rig-controll flrig2"

[fldigi.console.no-waterfall]: images/fldigi.console.no-waterfall.png "fldigi Console with no waterfall working"

[fldigi.console.vfo]: images/fldigi.console.vfo.png "fldigi Console (vfo portion)" 

[fldigi.console]: images/fldigi.png "fldigi Console"

[flrig.config.pool]: images/flrig.configure.poll.png "flrig Config/poll options - this may be a bug"

[flrig.config.restore]: images/flrig.configure.restore.png "flrig Config/restore options"

[flrig.config.tcpip]: images/flrig.configure.tcpip.png "flrig Config/tcpip options"

[flrig.config.xcvr]: images/flrig.configure.xcvr.png "flrig Config/xcvr options"

[flrig.not.responding]: images/flrig.not.responding.png "Not Connected"

[flrig.config.ptt-generic]: images/flrig.configure.ptt-generic.png "flrig Config/PTT-Generic options"

[flrig.console]: images/flrig.png "Unconfigured Console"

[TSL2591]: https://github.com/DonBower/HamGoBox/blob/master/Images/TSL2591.jpg "High Dynamic Range Digital Light Sensor"

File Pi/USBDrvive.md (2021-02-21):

***

# External Storage (USB Stick)

In addition to the RaspberryPi, we need a storage device for all the data we will collect.
I'm not really sure at this time what size we need, so I'll go big, and use the [Samsung 32GB USB 3.0 Flash Drive Fit](https://www.amazon.com/Samsung-Flash-Drive-MUF-32BB-AM/dp/B013CCTOC2) from amazon.
First, find any unintentional mounts from plugging in the flash drive. (Note: the procedures below assume the device is /dev/sda, and therefore the partition is /dev/sda1.  Should the next command display a different device, you must adapt as required.)

  ```
  df -h
  ```

look for devices mounted to /dev/sda*, and unmount them.  For example if you see a directory mounted on /dev/sda1, as I did with my Samsung-Flash-Drive-MUF-32BB, then run this command to unmount it.

<br>

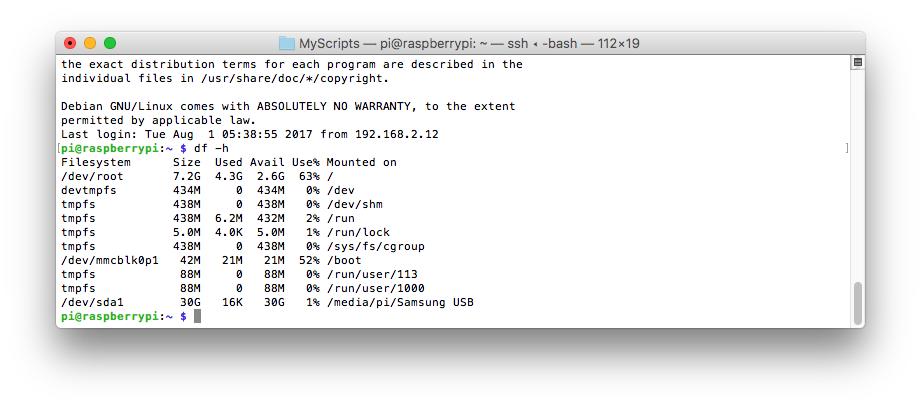
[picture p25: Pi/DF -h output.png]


[DFH]: https://github.com/DonBower/HamGoBox/blob/master/Pi/DF%20-h%20output.png "df -h output example"

<br>

  ```
  sudo umount /dev/sda1
  ```

Next, *and this is destructive*, remove any partitions, and create a new, fresh one.

  ```
  sudo fdisk /dev/sda
  p # This will print all the partitions
  d # This will delete the last partition. Repeat as required to delete all partitions
  n # This will create a new partition.  Take all the defaults.
  w # Rewrite the new partition table.
  ```

Now, format the new partition for ext4 file system.

  ```
  sudo mkfs.ext4 -L HamGoBox /dev/sda1
  ```

The follow steps will allow the USB drive to be persistently mounted.

```
sudo mkdir /mnt/usbstick
sudo chmod 777 /mnt
sudo chmod 777 /mnt/usbstick
sudo tee -a /etc/fstab <<EOF
LABEL=HamGoBox     /mnt/usbstick   ext4    defaults          0       1
EOF
sudo mount -a
```

You should now be able to `df -h` and see the /dev/sda1 mounted on /mnt/usbstick.

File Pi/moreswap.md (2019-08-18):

How to change Raspberry Pi's Swapfile Size on Raspbian
11 Feb 2015
Written by Shane Pfaffly
Reason Why
Ever get the dreaded error:

Virtual memory exhausted: Cannot allocate memory
With the first iterations of Raspberry Pi the Model A comes with 256mb of memory. While the Raspberry Pi B comes with a modest 512mb of memory. For most applications this amount of memory is actually quiet a bit. As soon as you start compiling your own binaries this amount starts to seem dismal.

*Insert reason why swap on flash-based memory is bad here.

Limitations
The Raspbian distribution comes with a 100mb swapfile. This is actually a bit on the small side. A general rule of thumb is swapfile size should be about twice as much as the available RAM on the machine. In the examples below I have a Raspberry Pi B+. So the amount of swap I use is 1024mb.

Commands
We will change the configuration in the file */etc/dphys-swapfile *:

sudo nano /etc/dphys-swapfile
The default value in Raspbian is:

CONF_SWAPSIZE=100
We will need to change this to:

CONF_SWAPSIZE=1024
Then you will need to stop and start the service that manages the swapfile own Rasbian:

sudo /etc/init.d/dphys-swapfile stop
sudo /etc/init.d/dphys-swapfile start
You can then verify the amount of memory + swap by issuing the following command:

free -m
The output should look like:

total     used     free   shared  buffers   cached
Mem:           435       56      379        0        3       16
-/+ buffers/cache:       35      399
Swap:         1023        0     1023
Finished!
That should be enough swap to complete any future compiles I may do in the future.

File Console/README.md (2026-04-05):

# Install 3.5" PiTFT
cd ~
sudo pip3 install --upgrade adafruit-python-shell click==7.0
sudo apt-get install -y git
git clone https://github.com/adafruit/Raspberry-Pi-Installer-Scripts.git
cd Raspberry-Pi-Installer-Scripts
sudo python3 adafruit-pitft.py --display=35r --rotation=90 --install-type=console --reboot=yes
Rebooting
If/When it asks you to reboot, then choose yes because the setting won't take full effect until you do so.

# Autostart
To start the four programs automatically on boot (useful for use when you have no access to the pi in the field), edit the crontab (`sudo crontab -e -u root`) and add the following line:

```
@reboot /home/don/Developer/HamGoBox/Console/dspout.sh 1> /home/don/dspout.sh.errlog.txt 2>&1
```

# Display
Here is the display:
note: the GPS values are captured before satellite lock.

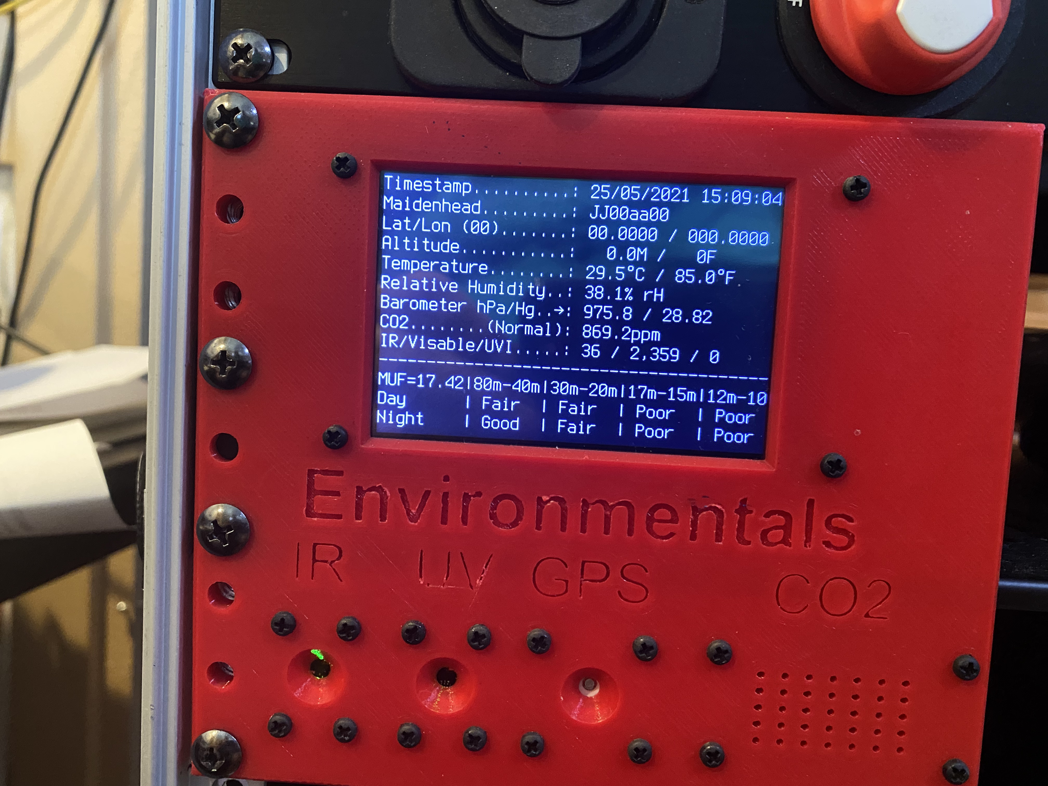
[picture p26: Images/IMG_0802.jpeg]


[hampiwx]: https://github.com/DonBower/HamGoBox/blob/master/Images/IMG_0802.jpeg "HamPiWX Console"

from a keyboard, use the command dspkill.sh to kill the auto-restart and python process

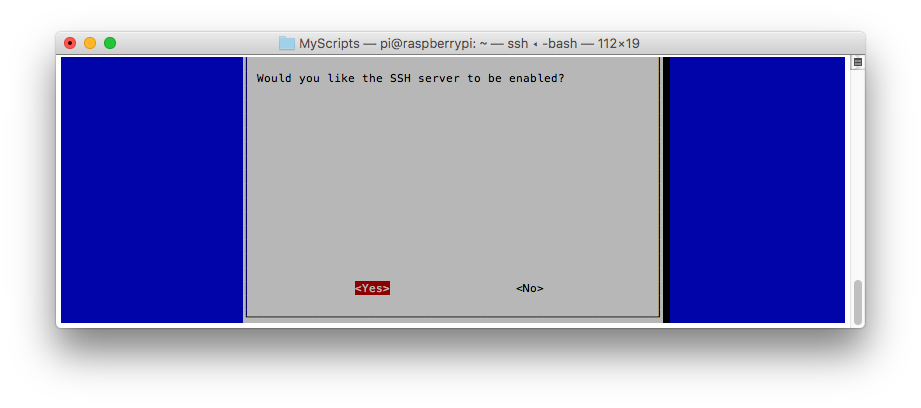
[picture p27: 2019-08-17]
Images/Enable SSH.png

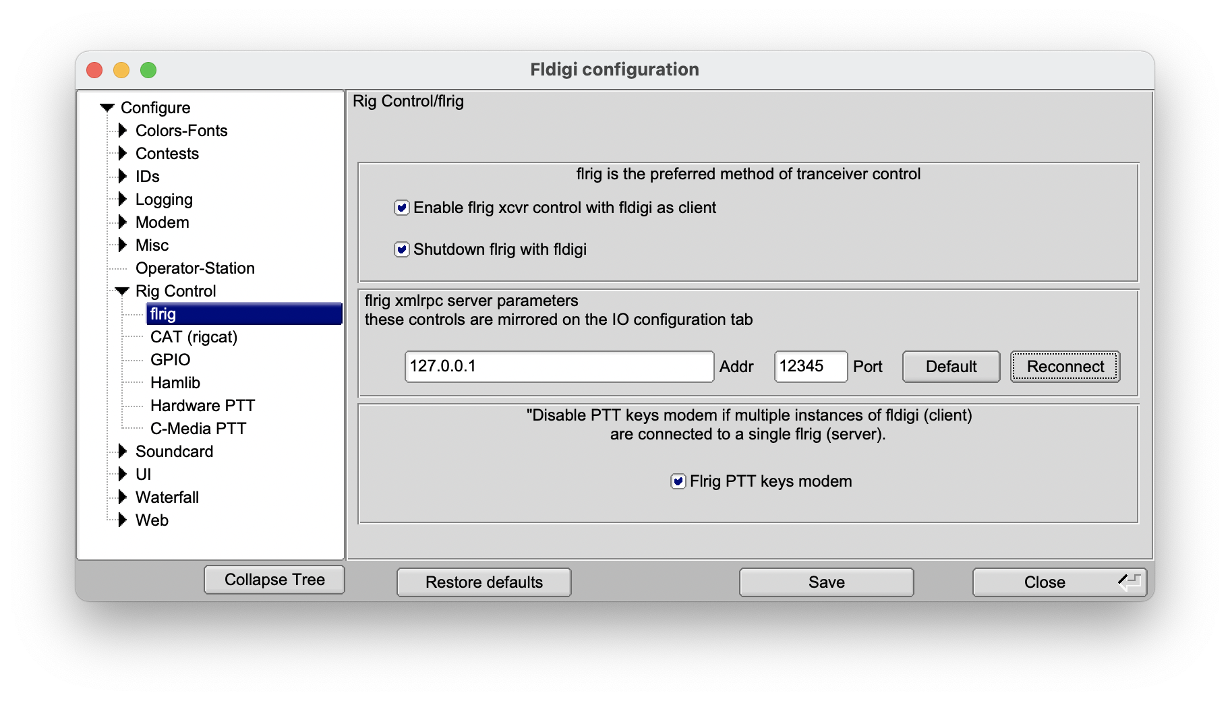
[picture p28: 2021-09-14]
fldigi/images/fldigi.configure.rig-control.flrig.png

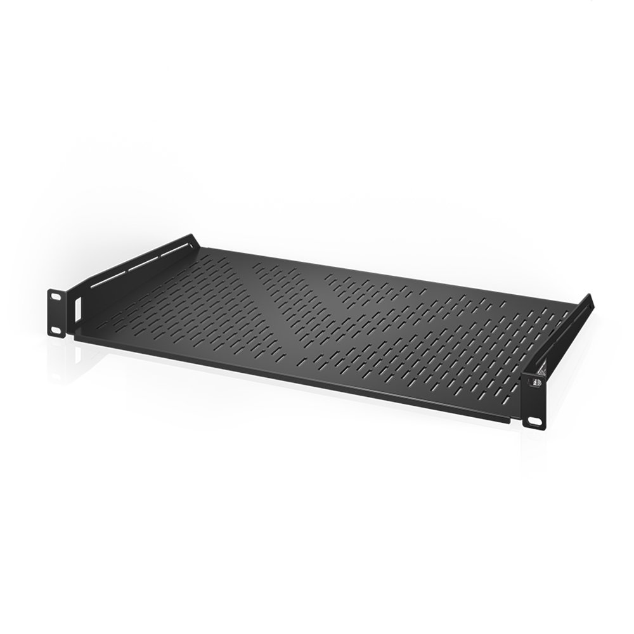
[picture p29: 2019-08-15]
Images/Shelf.jpg

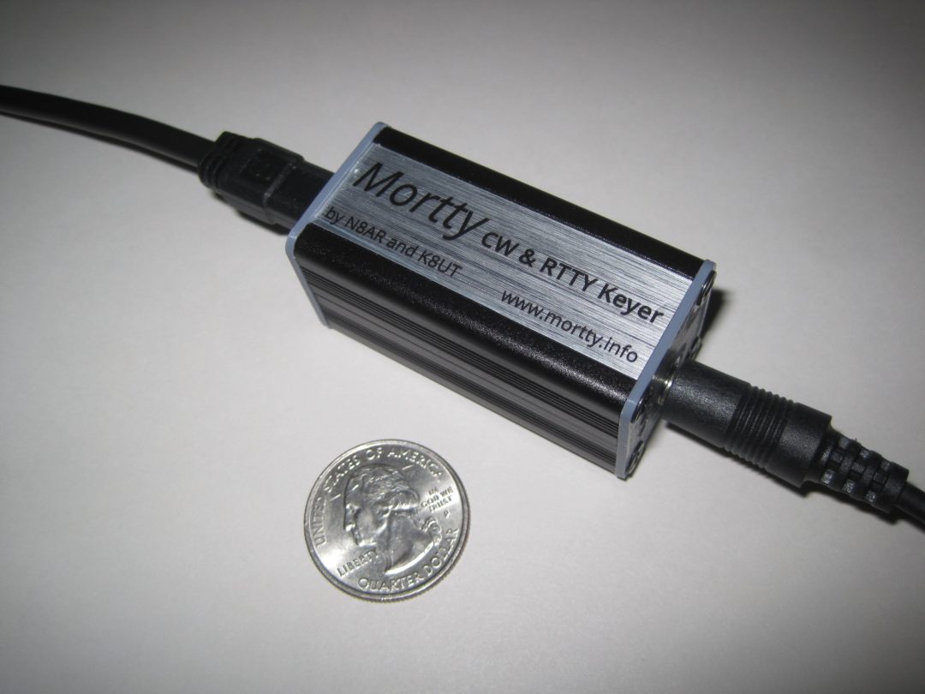
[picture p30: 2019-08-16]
Images/MorttyWithQuarter-1080x810.jpg

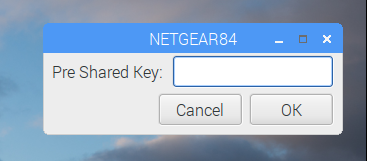
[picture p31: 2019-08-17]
Images/EnterWiFiPassword.png

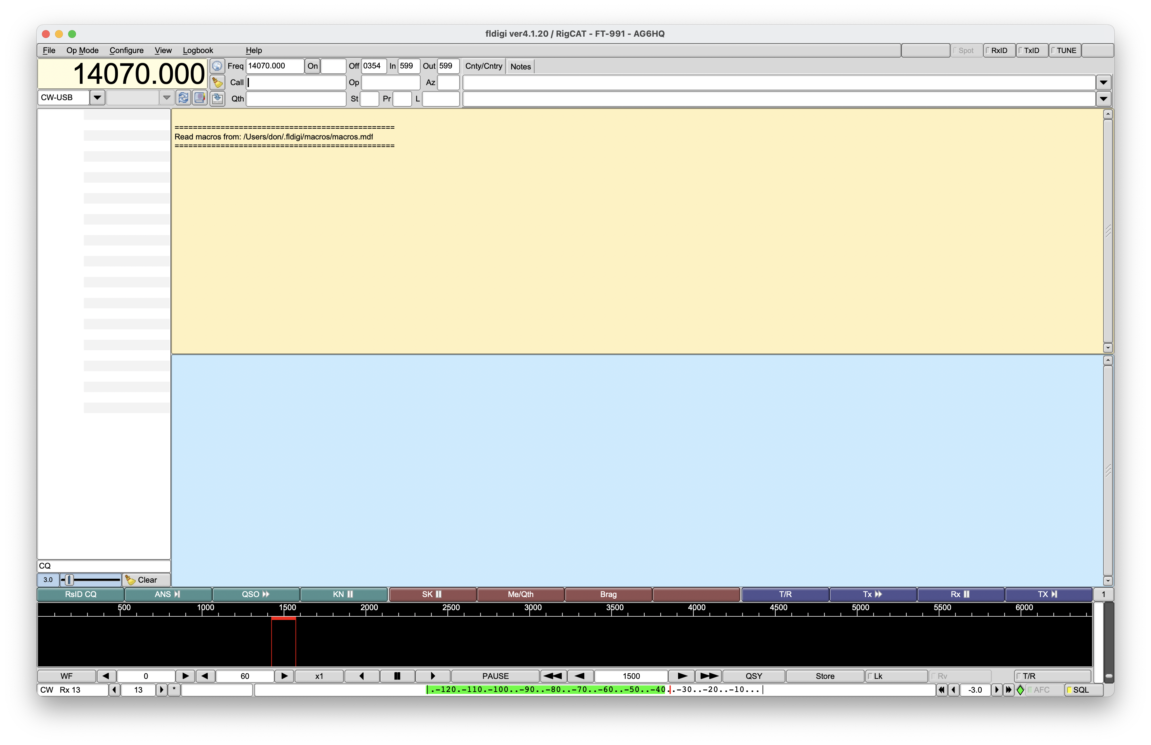
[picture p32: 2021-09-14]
fldigi/images/fldigi.png

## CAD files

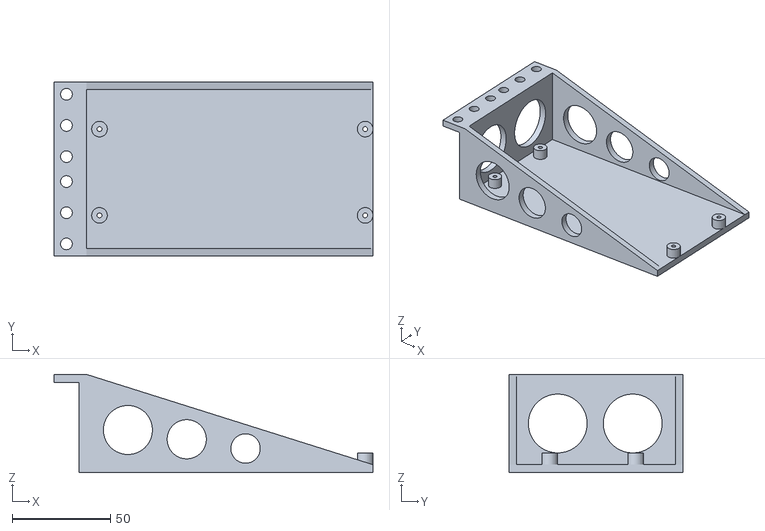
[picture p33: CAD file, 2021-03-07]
Thingiverse/WMR_RigRunner_Rack_Bracket v2.stl
162.7 x 88.9 x 50.0

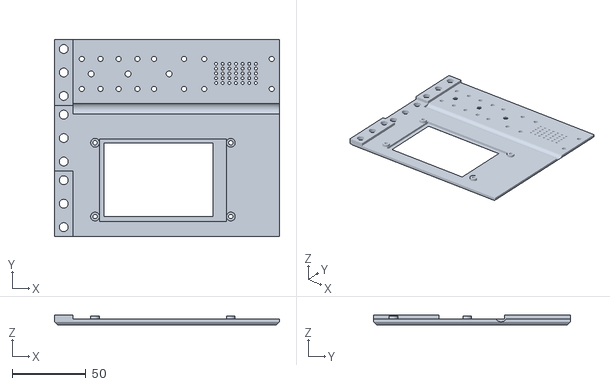
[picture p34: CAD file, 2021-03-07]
Thingiverse/Environmental_TFT_Bracket v35.stl
152.5 x 133.4 x 6.50

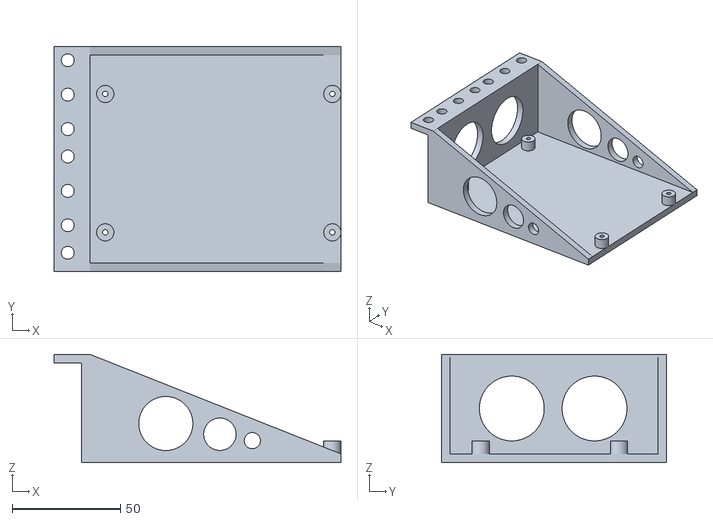
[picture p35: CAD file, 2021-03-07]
Thingiverse/WMR_EPG_Rack_Bracket v2.stl
132.7 x 104.0 x 50.0

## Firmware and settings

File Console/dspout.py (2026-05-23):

#!/usr/bin/python3
import os
from os import path
import sys
import time
from datetime import datetime
from datetime import timedelta
import requests
from requests.exceptions import ConnectTimeout, HTTPError, ReadTimeout, RequestException, Timeout, TooManyRedirects, URLRequired
import xml.etree.ElementTree as ET
import json
import board
import busio
import adafruit_gps
import adafruit_bmp3xx
import adafruit_hts221
import adafruit_ltr390
import adafruit_tsl2591
import adafruit_scd30

xmlFile = '/tmp/solarrss.xml'
now = datetime.now()
freshDate = now + timedelta(hours = 12)

#last_print = time.monotonic()

i2c = busio.I2C(board.SCL, board.SDA)
bmpJSONFileName = "/home/don/bmpData.json"
#
# Try GPS Board
#
gps = "noSensor"
try:
    gps = adafruit_gps.GPS_GtopI2C(i2c, debug=False)  # Use I2C interface
except:
    gps = "noSensor"

if gps == "noSensor":
    hasGPS = False
else:
    hasGPS = True
    gps.send_command(b"PMTK314,0,1,0,1,0,0,0,0,0,0,0,0,0,0,0,0,0,0,0") # We only want GGA and RMC sentances...
    gps.send_command(b"PMTK220,1000") # Set Update rate to 1 second

print("GPS Sensor Present: " + str(hasGPS))

bmp = "noSensor"
try:
    bmp                          = adafruit_bmp3xx.BMP3XX_I2C(i2c)
except:
    bmp                          = "noSensor"

if bmp == "noSensor":
    hasBMP                       = False
else:
    hasBMP                       = True
    bmp.pressure_oversampling    = 8
    bmp.temperature_oversampling = 2
    firstHPA                     = 0
    previousMin                  = ""

print("BMP3XX Sensor Present: " + str(hasBMP))

try:
    hts                          = adafruit_hts221.HTS221(i2c)
except:
    hts                          = "noSensor"

if hts == "noSensor":
    hasHTS                       = False
else:
    hasHTS                       = True
    bmp.pressure_oversampling    = 8
    bmp.temperature_oversampling = 2

print("HTS221 Sensor Present: " + str(hasHTS))

try:
    ltr                          = adafruit_ltr390.LTR390(i2c)
except:
    ltr                          = "noSensor"

if ltr == "noSensor":
    hasLTR                       = False
else:
    hasLTR                       = True
    ltr.gain                     = 1
    ltr.resolution               = 4
    ltr.measurement_delay        = 2

print("LTR390 Sensor Present: " + str(hasLTR))

try:
    tsl                          = adafruit_tsl2591.TSL2591(i2c)
except:
    tsl                          = "noSensor"

if tsl == "noSensor":
    hasTSL                       = False
else:
    hasTSL                       = True
    # You can optionally change the gain and integration time:
    # tsl.gain = adafruit_tsl2591.GAIN_LOW (1x gain)
    # tsl.gain = adafruit_tsl2591.GAIN_MED (25x gain, the default)
    # tsl.gain = adafruit_tsl2591.GAIN_HIGH (428x gain)
    # tsl.gain = adafruit_tsl2591.GAIN_MAX (9876x gain)
    # tsl.integration_time = adafruit_tsl2591.INTEGRATIONTIME_100MS (100ms, default)
    # tsl.integration_time = adafruit_tsl2591.INTEGRATIONTIME_200MS (200ms)
    # tsl.integration_time = adafruit_tsl2591.INTEGRATIONTIME_300MS (300ms)
    # tsl.integration_time = adafruit_tsl2591.INTEGRATIONTIME_400MS (400ms)
    # tsl.integration_time = adafruit_tsl2591.INTEGRATIONTIME_500MS (500ms)
    # tsl.integration_time = adafruit_tsl2591.INTEGRATIONTIME_600MS (600ms)

print("TSL2591 Sensor Present: " + str(hasTSL))

try:
    scd                          = adafruit_scd30.SCD30(i2c)
except:
    scd                          = "noSensor"

if scd == "noSensor":
    hasSCD                       = False
else:
    hasSCD                       = True
    thisCO2                      = 0.0

print("SCD30 Sensor Present: " + str(hasSCD))

#f = open('/dev/tty1','w')
#sys.stdout = f

#
# Clear the Screen
#
#os.system("echo clear > /dev/tty1")
def clearScreen():
    print(chr(27) + "[2J")

#
# Print Timestamp
#
def printTimeStamp():
    now = datetime.now()
    timeStampNow = now.strftime("%d/%m/%Y %H:%M:%S")
    print("Timestamp..........: " + timeStampNow)

#
# Convert Decimal Degrees to degrees, minutes, and seconds
#
def getSexagesimal(decDegrees, latlon):
    thisDegree = int(abs(decDegrees))
    decMinSec  = abs(decDegrees) - thisDegree
    thisMin    = int(decMinSec * 60)
    decSec     = decMinSec - (thisMin / 60)
    thisSec    = round((decSec * 3600), 3)
    thisSexagesimal  = str(thisDegree) + '° '
    thisSexagesimal += str(thisMin).zfill(2) + '\' '
    thisSexagesimal += str(thisSec).zfill(2) + '" '
    if decDegrees >= 0:
        thisSexagesimal += str(latlon[0])
    else:
        thisSexagesimal += str(latlon[1])
    return thisSexagesimal

#
# Print GPS Latitude, Longitude and Maidenhead
#
def getMaidenHead(latitude, longitude):
    maxMaiden  = 4
    A          = ord('A')
    a          = divmod(longitude + 180,20)
    b          = divmod(latitude + 90,10)
    maidenHead = chr(A + int(a[0])) + chr(A + int(b[0]))
    longitude  = a[1]/2
    latitude   = b[1]
    i          = 1
    while i    < maxMaiden:
        i                   += 1
        a                    = divmod(longitude,1)
        b                    = divmod(latitude,1)
        if not(i%2):
            maidenHead      += str(int(a[0]))+str(int(b[0]))
            longitude        = 24*a[1]
            latitude         = 24*b[1]
        else:
            tmp              = i+1
            tmpString        = chr(A+int(a[0]))+chr(A+int(b[0]))
            # Every other set is lowercase
            if not(tmp%4):
                maidenHead  += tmpString.lower()
            else:
                maidenHead  += tmpString
            longitude        = 10*a[1]
            latitude         = 10*b[1]
    return maidenHead

def printGPS():
    gps.update()
#    current = time.monotonic()
#    if current - last_print >= 0.50:
#    last_print = current
    thisLat = gps.latitude
    thisLon = gps.longitude
    thisAltM = gps.altitude_m
    thisSatCount = gps.satellites
    if not isinstance(thisLat, float):
        thisLat = 0.0
    if not isinstance(thisLon, float):
        thisLon = 0.0
    if not isinstance(thisAltM, float):
        thisAltM = 0.0
        thisAltF = 0.0
    else:
        thisAltF = thisAltM * 3.28084
    if not isinstance(thisSatCount, int):
        thisSatCount = 0

#    thisLat = 34
#    thisLon = -117

    print(f'Maidenhead.........: {getMaidenHead(thisLat, thisLon):8s}                   '[:40], end='')
    print(f'Lat/Lon ({thisSatCount:02d}).......: {thisLat:07.4f} / {thisLon:08.4f}                   '[:40], end='')
#    print(f'Lat/Lon ({thisSatCount:02d}).......: {getSexagesimal(thisLat,["N","S"]):16s} / {getSexagesimal(thisLon,["N","S"]):17s}                   '[:40], end='')
    print(f'Altitude...........: {thisAltM:5,.1f}M / {thisAltF:3,.0f}F                   '[:40], end='')

def printBMP():
    global firstHPA, previousMin, haveFullMinute
    now = datetime.now()
    thisMin = now.strftime("%H:%M")
    thisDate = now.strftime("%Y-%m-%d")

    if path.exists(bmpJSONFileName):
        with open(bmpJSONFileName, "r") as jsonFile:
            try:
                bmpJSON = json.load(jsonFile)
            except:
                bmpJSON = None

            if bmpJSON is None:
                bmpJSON = json.loads('{}')

            if thisMin in bmpJSON:
                thisMinData = bmpJSON.get(thisMin)
            else:
                thisMinData = json.loads('{}')
                thisMinData['Date'] = thisDate
                thisMinData['HPATotal'] = 0
                thisMinData['Samples'] = 0
                thisMinData['Trend'] = '→'
    else:
        bmpJSON = json.loads('{}')
        thisMinData = json.loads('{}')
        thisMinData['Date'] = thisDate
        thisMinData['HPATotal'] = 0
        thisMinData['Samples'] = 0
        thisMinData['Trend'] = '→'

    thisMinHPA = thisMinData['HPATotal']
    samplesCount = thisMinData['Samples']
    jsonDate = thisMinData['Date']

    thisHPA = bmp.pressure
#
# Need a 12 hour clock to check if thisMinData is old
#   (because of wraparound or multiday idle)
#   - jsonDate + thisMin > 12 hours thisDate + thisMin is ok.
#
    if thisMin == previousMin:
        samplesCount = samplesCount + 1
        thisMinHPA = thisMinHPA + thisHPA
        minuteAvgHPA = thisMinHPA / samplesCount
    else:
        if samplesCount <= 60:
            haveFullMinute = False
        else:
            haveFullMinute = True
        samplesCount = 1
        thisMinHPA = thisHPA
        minuteAvgHPA = thisHPA
        previousMin = thisMin

    if firstHPA == 0 or not haveFullMinute:
        firstHPA = minuteAvgHPA

    if thisHPA > firstHPA:
        thisHPATrend = '↑'
    else:
        if thisHPA < firstHPA:
            thisHPATrend = '↓'
        else:
            thisHPATrend = '→'


    thisMinData['HPATotal'] = thisMinHPA
    thisMinData['Samples'] = samplesCount
    thisMinData['Trend'] = thisHPATrend
    thisMinData['Date'] = thisDate
    bmpJSON[thisMin] = thisMinData

    with open(bmpJSONFileName, "w") as jsonFile:
        json.dump(bmpJSON, jsonFile, indent=4)

    thisHG = thisHPA / 33.864
    print(f'Barometer hPa/Hg..{thisHPATrend:1s}: {thisHPA:5,.1f} / {thisHG:5.2f}                   '[:40])

def printHTS():
    thisHumidity = hts.relative_humidity
    thisTempC    = hts.temperature
    thisTempF    = ((9.0 / 5.0) * thisTempC + 32)
#    °C/°F
#    ℃/℉ - These do not print.
    print(f'Temperature........: {thisTempC:4.1f}°C /{thisTempF:5.1f}°F                   '[:40])
    print(f'Relative Humidity..: {thisHumidity:4.1f}% rH                   '[:40])

def printLTR():
    thisUV           = ltr.uvs
#    thisUVi          = int(round((thisUV / 95), 0))
    thisUVi          = ltr.uvi
#    thisAmbient      = ltr.light
    thisAmbient      = ltr.lux
    print(f'UVa EMF / UVI......: {thisUV:1,d}µW/cm^2 / {thisUV:1,d}UVi                   '[:40])
    print(f'Ambient Light......: {thisAmbient:1,.1f}                   '[:40])

def printTSL():
    thisIR           = tsl.infrared
    thisVis          = tsl.visible
    thisLux          = tsl.lux
    thisFullSpectrum = tsl.full_spectrum
    print(f'Visable Light......: {thisVis:4,d}                   '[:40])
    print(f'Infrared Light.....: {thisIR:1,d}                   '[:40])

def printLight():
    if hasTSL:
        thisIR       = tsl.infrared
        thisVis      = tsl.visible/1000
    else:
        thisIR       = 0
        thisVis      = 0
    if hasLTR:
        thisUV       = ltr.uvs
        thisUVi      = ltr.uvi
        if thisVis == 0:
            thisVis  = ltr.lux * 1000
    if hasTSL and hasLTR:
        print(f'IR/Visable/UVI.....: {thisIR:1,d} / {thisVis:1,.0f} / {thisUV:1,d}                   '[:40])
    elif hasLTR:
        print(f'Visable/UVI........: {thisVis:1,.0f} / {thisUV:1,d}                   '[:40])
    elif hasTSL:
        print(f'IR/Visable.........: {thisIR:1,d} / {thisVis:1,.0f}                   '[:40])


def printSCD():
    global thisCO2

    try:
        ready = scd.data_available
        if ready:
            thisCO2 = scd.CO2
            status = "OK"
        else:
            status = "NO DATA"
            thisCO2 = -1.0
    except Exception as e:
        status = "ERROR"
        thisCO2 = -2.0
        print(repr(e), file=sys.stderr)

    print(f'CO2......{status:10s}: {thisCO2:3,.1f}ppm '[:40], end='')
    
def bandIndex(thisBand):
    switcher={
        '80m-40m':0,
        '30m-20m':1,
        '17m-15m':2,
        '12m-10m':3
        }
    return switcher.get(thisBand,"Invalid Band")

def timeIndex(thisTime):
    switcher={
            'day':0,
            'night':1
         }
    return switcher.get(thisTime,"Invalid Time")

def getRSS(xmlFile):
    # url of rss feed
    url = 'http://www.hamqsl.com/solarrss.php'
    # creating HTTP response object from given url
    try:
        resp = requests.get(url)
        # saving the xml file
        with open(xmlFile, 'wb') as f:
            f.write(resp.content)
    except RequestException:
        print("RequestException for " + url + "\n")
        sys.stderr.write("RequestException for " + url + "\n")
    except ConnectionError:
        print("Connection error for " + url + "\n")
        sys.stderr.write("Connection error for " + url + "\n")
    except HTTPError:
        print("HTTP request returned an unsuccessful status code for " + url + "\n")
        sys.stderr.write("HTTP request returned an unsuccessful status code for " + url + "\n")
    except URLRequired:
        print("A valid URL is required for " + url + "\n")
        sys.stderr.write("A valid URL is required for " + url + "\n")
    except TooManyRedirects:
        print("Too many redirects for " + url + "\n")
        sys.stderr.write("Too many redirects for " + url + "\n")
    except ConnectTimeout:
        print("The request timed out while trying to connect to the remote server. " + url + "\n")
        sys.stderr.write("The request timed out while trying to connect to the remote server. " + url + "\n")
    except ReadTimeout:
        print("The server did not send any data in the allotted amount of time for url " + url + "\n")
        sys.stderr.write("The server did not send any data in the allotted amount of time for url " + url + "\n")
    except Timeout:
        print("The request timed out for url " + url + "\n")
        sys.stderr.write("The request timed out for url " + url + "\n")
#    finally:
#        print("Failed to cURL " + url + "\n")
#        sys.stderr.write("Failed to cURL " + url + "\n")
 
def parseRSS(xmlFile):
    global thisMUF, theseConditions, freshDate
    # create element tree object
    tree = ET.parse(xmlFile)
    # get root element
    root = tree.getroot()

    fileDate=root.findall('./channel/item/solar/solardata/updated')[0].text
    rssDate=datetime.strptime(fileDate," %d %b %Y %H%M %Z")
    freshDate = rssDate + timedelta(hours = 12)

    solarData = root.findall('./channel/item/solar/solardata')
    thisMUF=root.findall('./channel/item/solar/solardata/muf')[0].text
    # create empty list for news items
    theseConditions = [['' for x in range(4)] for y in range(2)]
    # iterate news items
    for band in root.findall('./channel/item/solar/solardata/calculatedconditions/band'):
        thisBand=band.attrib['name']
        thisTime=band.attrib['time']
        thisCondition=band.text
        theseConditions[timeIndex(thisTime)][bandIndex(thisBand)] = thisCondition

def printSolar():
    print(f'------------------------------------------------                    '[:40])
    print(f'MUF={thisMUF:5s}|80m-40m|30m-20m|17m-15m|12m-10m                    '[:40])
    print(f'Day      |{theseConditions[0][0]:^7s}|{theseConditions[0][1]:^7s}|{theseConditions[0][2]:^7s}|{theseConditions[0][3]:^7s}                    '[:40])
    print(f'Night    |{theseConditions[1][0]:^7s}|{theseConditions[1][1]:^7s}|{theseConditions[1][2]:^7s}|{theseConditions[1][3]:^7s}                    '[:40], end='')

if not path.exists(xmlFile):
    getRSS(xmlFile)

if path.exists(xmlFile):
    parseRSS(xmlFile)

clearScreen()
while True:
#    sys.stdout.write("\x1b[2J\x1b[H") # Position to top
    sys.stdout.write("\x1b[H") # Position to top
    now = datetime.now()
    printTimeStamp()
    if not divmod(int(datetime.now().strftime("%S")),6)[1]:
        if hasGPS:
            printGPS()
        if hasHTS:
            printHTS()
        if hasBMP:
            printBMP()
        if hasSCD:
            printSCD()
        if hasLTR or hasTSL:
            printLight()
#        if hasLTR:
#            printLTR()
#        if hasTSL:
#            printTSL()
        if now > freshDate:
            try:
                getRSS(xmlFile)
                parseRSS(xmlFile)
            finally:
                print("Failed to getRSS(" + xmlFile + ")")

        if path.exists(xmlFile):
            printSolar()

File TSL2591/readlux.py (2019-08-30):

#!/usr/bin/env python3
import tsl2591
import time

BASEDIR = "/mnt/usbstick/data"
TimeStampStr = time.strftime("%Y-%m-%d %H:%M:%S")
DATAFILE = '{0:s}/tsldata_{1:s}.txt'.format(BASEDIR,TimeStampStr)

F1 = open(DATAFILE, "w", 1) # Open File, write to disk every line.

VISIBLE = 2  # channel 0 - channel 1
INFRARED = 1  # channel 1
FULLSPECTRUM = 0  # channel 0

GAIN_LOW = 0x00  # low gain (1x)
GAIN_MED = 0x10  # medium gain (25x)
GAIN_HIGH = 0x20  # medium gain (428x)
GAIN_MAX = 0x30  # max gain (9876x)

tsl = tsl2591.Tsl2591()  # initialize

thisGain = tsl.get_gain()
print('This Gain is {}'.format(thisGain))

tsl.set_gain(GAIN_MED)

thisGain = tsl.get_gain()
print('New Gain is {}'.format(thisGain))

def setup():
    print("Setting up, please wait...")
    print("Open File {} for append".format(DATAFILE))
    print("{0:>10} {1:>10} {2:>10} {3:>10}".format('Time', 'Full Lux', 'Visiable', 'Infrared'))


def loop():
    while True:

        newfull = tsl.get_luminosity(FULLSPECTRUM)
        newlux = tsl.get_luminosity(VISIBLE)
        newir = tsl.get_luminosity(INFRARED)
        TimeStampStr = time.strftime("%Y-%m-%d %H:%M:%S")
        TimeStr = time.strftime("%H:%M:%S")

        print("{0:10} {1:10} {2:10} {3:10}".format(TimeStr,newfull, newlux, newir))
        F1.write('{0:20} {1:10} {2:10} {3:10}\n'.format(TimeStampStr, newfull, newlux, newir))
        time.sleep(1)
        timeseconds = int(time.strftime("%S"))
        while timeseconds%5 > 0:
            time.sleep(.2)
            timeseconds = int(time.strftime("%S"))


def destroy():
    F1.close()

if __name__ == "__main__":
    setup()
    try:
        loop()
    except KeyboardInterrupt:
        destroy()

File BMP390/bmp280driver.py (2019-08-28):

#coding: utf-8
import Adafruit_GPIO.I2C as I2C
import time
i2c = I2C
device=i2c.get_i2c_device(0x77) # address of BMP

# this value is necessary to calculate the correct height above sealevel
# its also included in airport wheather information ATIS named as QNH
# unit is hPa
QNH=1020
print("QNH:{:.0f}".format(QNH)+" hPA")

# power mode
# POWER_MODE=0 # sleep mode
# POWER_MODE=1 # forced mode
# POWER_MODE=2 # forced mode
POWER_MODE=3 # normal mode

# temperature resolution
# OSRS_T = 0 # skipped
# OSRS_T = 1 # 16 Bit
# OSRS_T = 2 # 17 Bit
# OSRS_T = 3 # 18 Bit
# OSRS_T = 4 # 19 Bit
OSRS_T = 5 # 20 Bit

# pressure resolution
# OSRS_P = 0 # pressure measurement skipped
# OSRS_P = 1 # 16 Bit ultra low power
# OSRS_P = 2 # 17 Bit low power
# OSRS_P = 3 # 18 Bit standard resolution
# OSRS_P = 4 # 19 Bit high resolution
OSRS_P = 5 # 20 Bit ultra high resolution

# filter settings
# FILTER = 0 #
# FILTER = 1 #
# FILTER = 2 #
# FILTER = 3 #
FILTER = 4 #
# FILTER = 5 #
# FILTER = 6 #
# FILTER = 7 #

# standby settings
# T_SB = 0 # 000 0,5ms
# T_SB = 1 # 001 62.5 ms
# T_SB = 2 # 010 125 ms
# T_SB = 3 # 011 250ms
T_SB = 4 # 100 500ms
# T_SB = 5 # 101 1000ms
# T_SB = 6 # 110 2000ms
# T_SB = 7 # 111 4000ms


CONFIG = (T_SB <<5) + (FILTER <<2) # combine bits for config
CTRL_MEAS = (OSRS_T <<5) + (OSRS_P <<2) + POWER_MODE # combine bits for ctrl_meas

# print ("CONFIG:",CONFIG)
# print ("CTRL_MEAS:",CTRL_MEAS)

BMP280_REGISTER_DIG_T1 = 0x88
BMP280_REGISTER_DIG_T2 = 0x8A
BMP280_REGISTER_DIG_T3 = 0x8C
BMP280_REGISTER_DIG_P1 = 0x8E
BMP280_REGISTER_DIG_P2 = 0x90
BMP280_REGISTER_DIG_P3 = 0x92
BMP280_REGISTER_DIG_P4 = 0x94
BMP280_REGISTER_DIG_P5 = 0x96
BMP280_REGISTER_DIG_P6 = 0x98
BMP280_REGISTER_DIG_P7 = 0x9A
BMP280_REGISTER_DIG_P8 = 0x9C
BMP280_REGISTER_DIG_P9 = 0x9E
BMP280_REGISTER_CHIPID = 0xD0
BMP280_REGISTER_VERSION = 0xD1
BMP280_REGISTER_SOFTRESET = 0xE0
BMP280_REGISTER_CONTROL = 0xF4
BMP280_REGISTER_CONFIG  = 0xF5
BMP280_REGISTER_STATUS = 0xF3
BMP280_REGISTER_TEMPDATA_MSB = 0xFA
BMP280_REGISTER_TEMPDATA_LSB = 0xFB
BMP280_REGISTER_TEMPDATA_XLSB = 0xFC
BMP280_REGISTER_PRESSDATA_MSB = 0xF7
BMP280_REGISTER_PRESSDATA_LSB = 0xF8
BMP280_REGISTER_PRESSDATA_XLSB = 0xF9

if (device.readS8(BMP280_REGISTER_CHIPID) == 0x58): # check sensor id 0x58=BMP280
    device.write8(BMP280_REGISTER_SOFTRESET,0xB6) # reset sensor
    time.sleep(0.2) # little break
    device.write8(BMP280_REGISTER_CONTROL,CTRL_MEAS) #
    time.sleep(0.2) # little break
    device.write8(BMP280_REGISTER_CONFIG,CONFIG)  #
    time.sleep(0.2)
    # register_control = device.readU8(BMP280_REGISTER_CONTROL) # check the controll register again
    # register_config = device.readU8(BMP280_REGISTER_CONFIG)# check the controll register again
    # print("config:",register_config)
    # print("control:",register_control)

    dig_T1 = device.readU16LE(BMP280_REGISTER_DIG_T1) # read correction settings
    dig_T2 = device.readS16LE(BMP280_REGISTER_DIG_T2)
    dig_T3 = device.readS16LE(BMP280_REGISTER_DIG_T3)
    dig_P1 = device.readU16LE(BMP280_REGISTER_DIG_P1)
    dig_P2 = device.readS16LE(BMP280_REGISTER_DIG_P2)
    dig_P3 = device.readS16LE(BMP280_REGISTER_DIG_P3)
    dig_P4 = device.readS16LE(BMP280_REGISTER_DIG_P4)
    dig_P5 = device.readS16LE(BMP280_REGISTER_DIG_P5)
    dig_P6 = device.readS16LE(BMP280_REGISTER_DIG_P6)
    dig_P7 = device.readS16LE(BMP280_REGISTER_DIG_P7)
    dig_P8 = device.readS16LE(BMP280_REGISTER_DIG_P8)
    dig_P9 = device.readS16LE(BMP280_REGISTER_DIG_P9)

    #print("dig_T1:",dig_T1," dig_T2:",dig_T2," dig_T3:",dig_T3)
    #print("dig_P1:",dig_P1," dig_P2:",dig_P2," dig_P3:",dig_P3)
    #print(" dig_P4:",dig_P4," dig_P5:",dig_P5," dig_P6:",dig_P6)
    #print(" dig_P7:",dig_P7," dig_P8:",dig_P8," dig_P9:",dig_P9)

    while True: # loop
        raw_temp_msb=device.readU8(BMP280_REGISTER_TEMPDATA_MSB) # read raw temperature msb
        raw_temp_lsb=device.readU8(BMP280_REGISTER_TEMPDATA_LSB) # read raw temperature lsb
        raw_temp_xlsb=device.readU8(BMP280_REGISTER_TEMPDATA_XLSB) # read raw temperature xlsb
        raw_press_msb=device.readU8(BMP280_REGISTER_PRESSDATA_MSB) # read raw pressure msb
        raw_press_lsb=device.readU8(BMP280_REGISTER_PRESSDATA_LSB) # read raw pressure lsb
        raw_press_xlsb=device.readU8(BMP280_REGISTER_PRESSDATA_XLSB) # read raw pressure xlsb

        raw_temp=(raw_temp_msb <<12)+(raw_temp_lsb<<4)+(raw_temp_xlsb>>4) # combine 3 bytes  msb 12 bits left, lsb 4 bits left, xlsb 4 bits right
        raw_press=(raw_press_msb <<12)+(raw_press_lsb <<4)+(raw_press_xlsb >>4) # combine 3 bytes  msb 12 bits left, lsb 4 bits left, xlsb 4 bits right
        # print("raw_press_msb:",raw_press_msb," raw_press_lsb:",raw_press_xlsb," raw_press_xlsb:",raw_press_xlsb)
        # print("raw_temp_msb:",raw_temp_msb,"  raw_temp_lsb:",raw_temp_lsb," raw_temp_xlsb:",raw_temp_xlsb)
        # print("raw_press",raw_press)

        # the following values are from the calculation example in the datasheet
        # this values can be used to check the calculation formulas
        # dig_T1=27504
        # dig_T2=26435
        # dig_T3=-1000
        # dig_P1=36477
        # dig_P2=-10685
        # dig_P3=3024
        # dig_P4=2855
        # dig_P5=140
        # dig_P6=-7
        # dig_P7=15500
        # dig_P8=-14600
        # dig_P9=6000
        # t_fine=128422.2869948
        # raw_temp=519888
        # raw_press=415148

        var1=(raw_temp/16384.0-dig_T1/1024.0)*dig_T2 # formula for temperature from datasheet
        var2=(raw_temp/131072.0-dig_T1/8192.0)*(raw_temp/131072.0-dig_T1/8192.0)*dig_T3 # formula for temperature from datasheet
        temp=(var1+var2)/5120.0 # formula for temperature from datasheet
        t_fine=(var1+var2) # need for pressure calculation

        var1=t_fine/2.0-64000.0 # formula for pressure from datasheet
        var2=var1*var1*dig_P6/32768.0 # formula for pressure from datasheet
        var2=var2+var1*dig_P5*2 # formula for pressure from datasheet
        var2=var2/4.0+dig_P4*65536.0 # formula for pressure from datasheet
        var1=(dig_P3*var1*var1/524288.0+dig_P2*var1)/524288.0 # formula for pressure from datasheet
        var1=(1.0+var1/32768.0)*dig_P1 # formula for pressure from datasheet
        press=1048576.0-raw_press # formula for pressure from datasheet
        press=(press-var2/4096.0)*6250.0/var1 # formula for pressure from datasheet
        var1=dig_P9*press*press/2147483648.0 # formula for pressure from datasheet
        var2=press*dig_P8/32768.0 # formula for pressure from datasheet
        press=press+(var1+var2+dig_P7)/16.0 # formula for pressure from datasheet

        altitude= 44330.0 * (1.0 - pow(press / (QNH*100), (1.0/5.255))) # formula for altitude from airpressure
        print("temperature:{:.2f}".format(temp)+" C  pressure:{:.2f}".format(press/100)+" hPa   altitude:{:.2f}".format(altitude)+" m")

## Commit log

2019-12-28 output current location on a single record
2021-01-24 sync up with mac
    [Board1.fzz]
2021-01-27 add TSL2591 Sensor
2021-01-27 add LTR390 Sensor
2021-01-27 forgot print
2021-01-27 no longer an estimated CO2 level
    [dspout.py]
2021-02-14 fix samples count
2021-02-16 add re-init if bmpJSON fails to load
    [dspout.py]
2021-02-18 print the rest only every 6 seconds
2021-02-19 all sensors
2021-02-20 inline comments screw up table
2021-02-21 past setup
    [Board1.fzz]
2021-02-21 add sensor test
2021-03-07 Add WMR & TFT Brackets
    [Environmental_TFT_Bracket v35.stl, WMR_EPG_Rack_Bracket v2.stl, WMR_RigRunner_Rack_Bracket v2.stl]
2021-06-27 Add Battery to Parts List
2021-10-30 add some error handling
    [dspout.py]
2021-11-03 add print
